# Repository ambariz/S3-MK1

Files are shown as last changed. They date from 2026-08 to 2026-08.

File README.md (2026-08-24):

# S3 MK-1

A compact Surveillance Security System built around a sensor-equipped cube and a wearable controller.

The S3 Cube monitors its surroundings using multiple sensors for motion, vibration, orientation, light, temperature, humidity, and sound. The data is sent to the S3 Watch, a small wearable controller with an OLED display and physical buttons for monitoring and controlling the cube.

The project includes custom PCBs designed in KiCad, custom component footprints, ESP8266 firmware, and fully 3D-printed enclosures designed in Onshape.

| S3 MK-1 Cube | S3 MK-1 Watch |
|---|---|
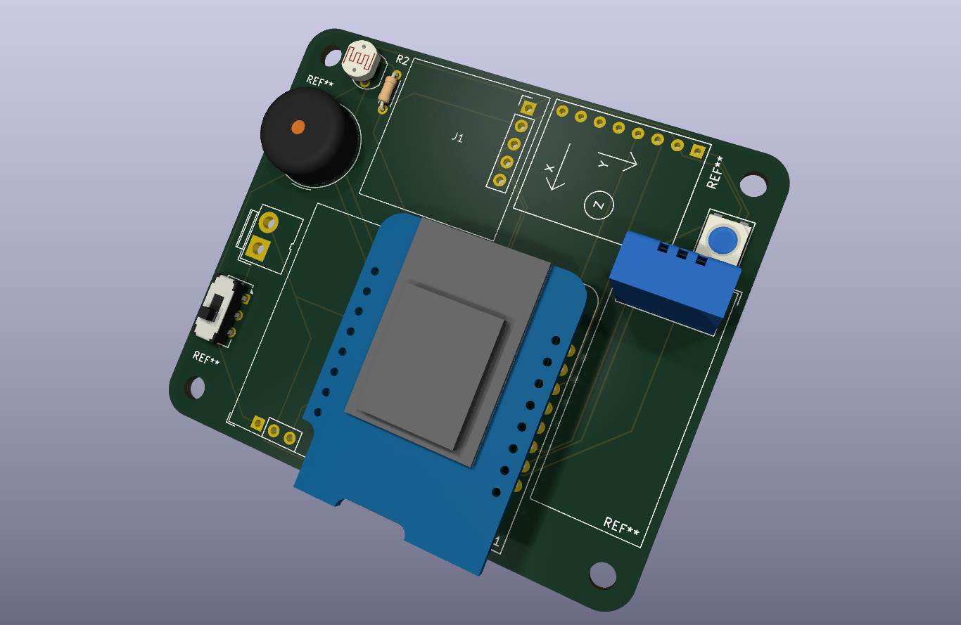
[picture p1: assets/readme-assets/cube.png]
S3 Cube
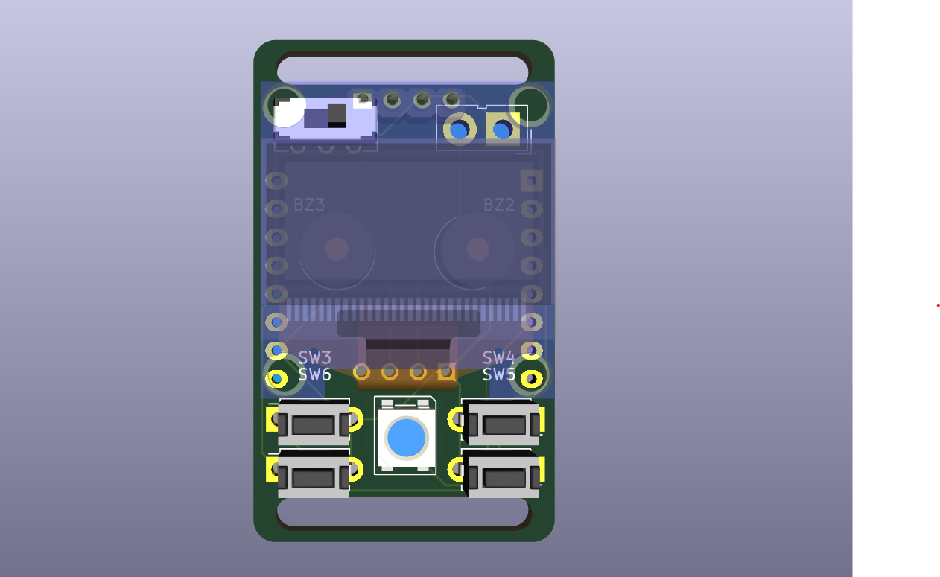
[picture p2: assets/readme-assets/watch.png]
S3 Watch
|  |  |

# Features

- Wireless S3 Cube MK-1 to S3 Watch MK-1 communication
- Motion / Presence detection
- Vibration detection
- Tilt / Orientation detection
- Sound detection
- Light detection
- Temperature & Humidity monitoring
- OLED display
- Physical button controls
- Arm / Disarm system
- Status indication
- Custom KiCad PCBs
- Custom KiCad footprints
- ESP8266 firmware
- 3D-printed enclosures
- Weighted self-orienting cube design
- 20mm watch strap support

## CAD

> **Note:**
> S3 Cube MK-1 enclosure is made for rolling in a plain surface. This's the reason the edges are with R10.

| S3 Cube MK-1 | S3 Watch MK-1 |
|---|---|
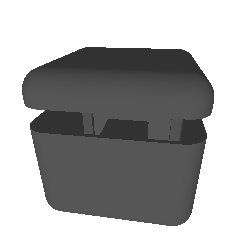
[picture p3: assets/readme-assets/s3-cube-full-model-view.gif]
S3 Cube
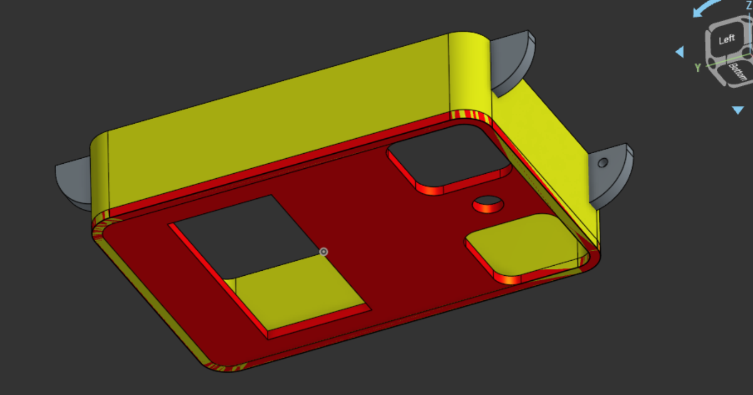
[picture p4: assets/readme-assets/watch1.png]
S3 Watch
|  |  |
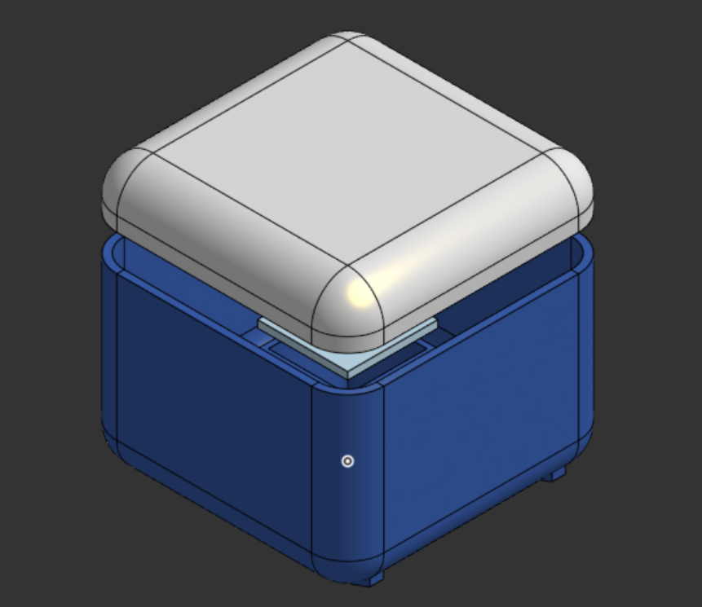
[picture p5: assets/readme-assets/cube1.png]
S3 Cube
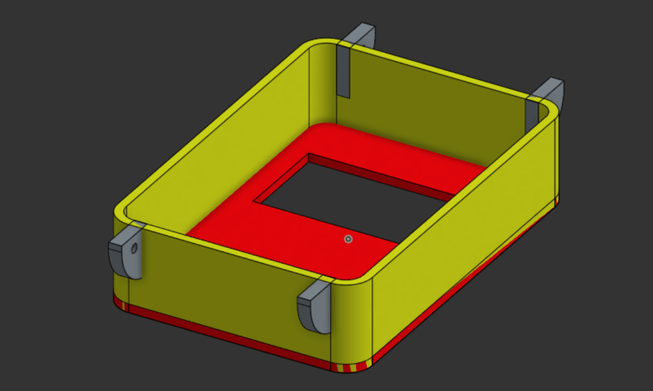
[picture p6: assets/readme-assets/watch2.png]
S3 Watch
|  |  |

## PCB

> **Note:**  
> The S3 Watch PCB is designed with a 20mm strap support, If you are 3D printing the enclosure for the watch, Feel free to break it with pliers.

| S3 MK-1 Cube PCB | S3 MK-1 Watch PCB |
|---|---|
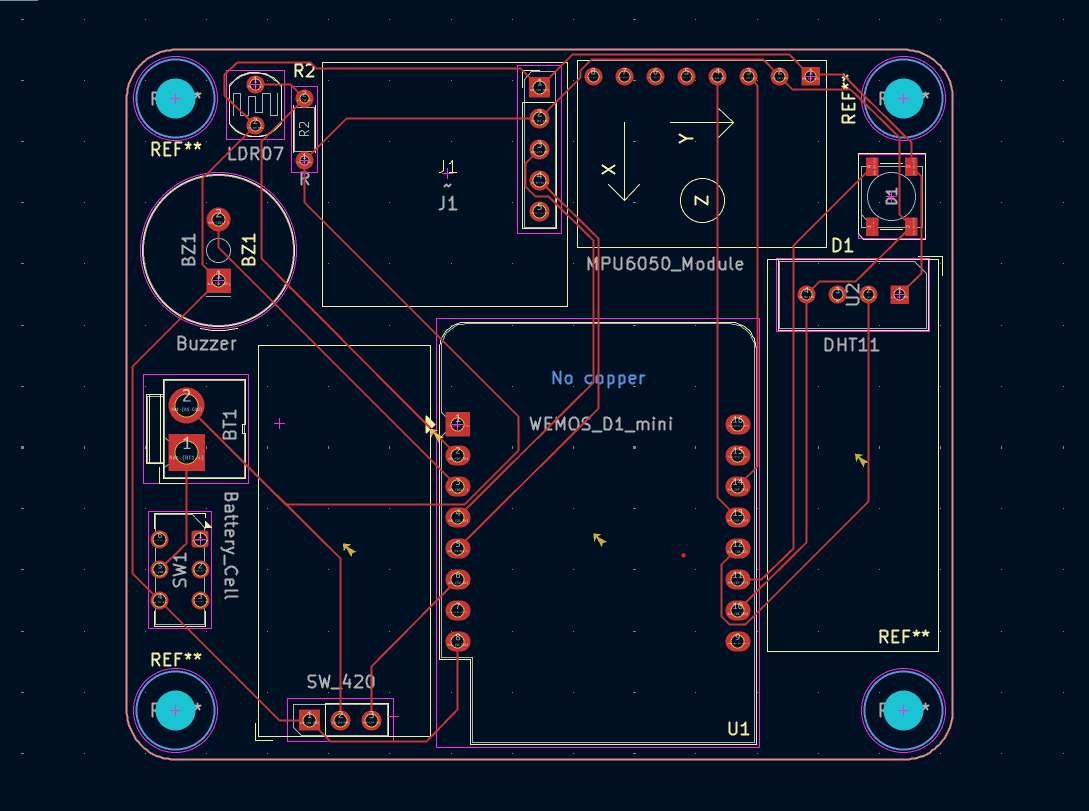
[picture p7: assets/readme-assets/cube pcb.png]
Cube PCB
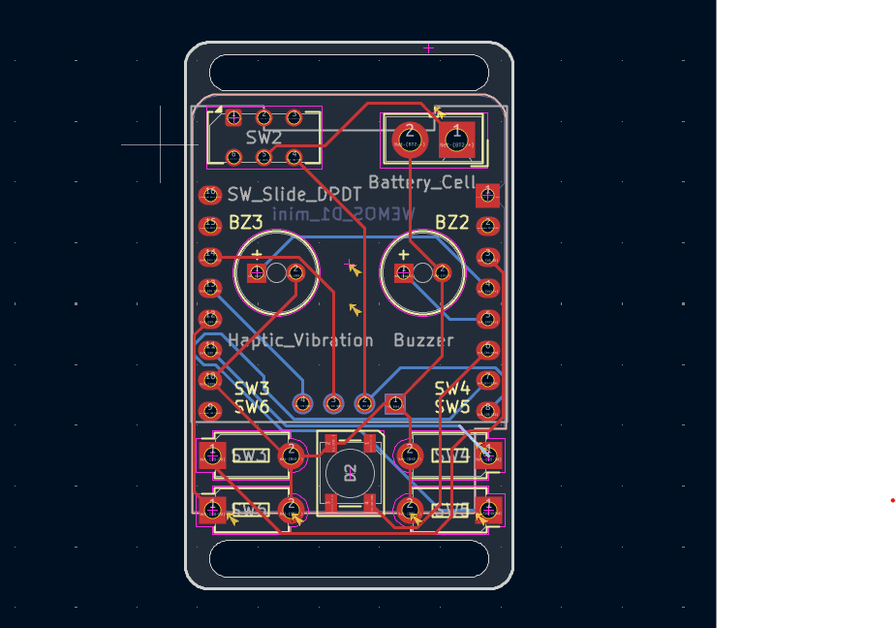
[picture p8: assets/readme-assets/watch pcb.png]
Watch PCB
|  |  |
| Cube PCB | Watch PCB |

## Schematic

> **Note:**  
> The preview images may be scaled down and lose detail. Use the journal.md for a clear, full-resolution view.

| S3 MK-1 Cube | S3 MK-1 Watch |
|---|---|
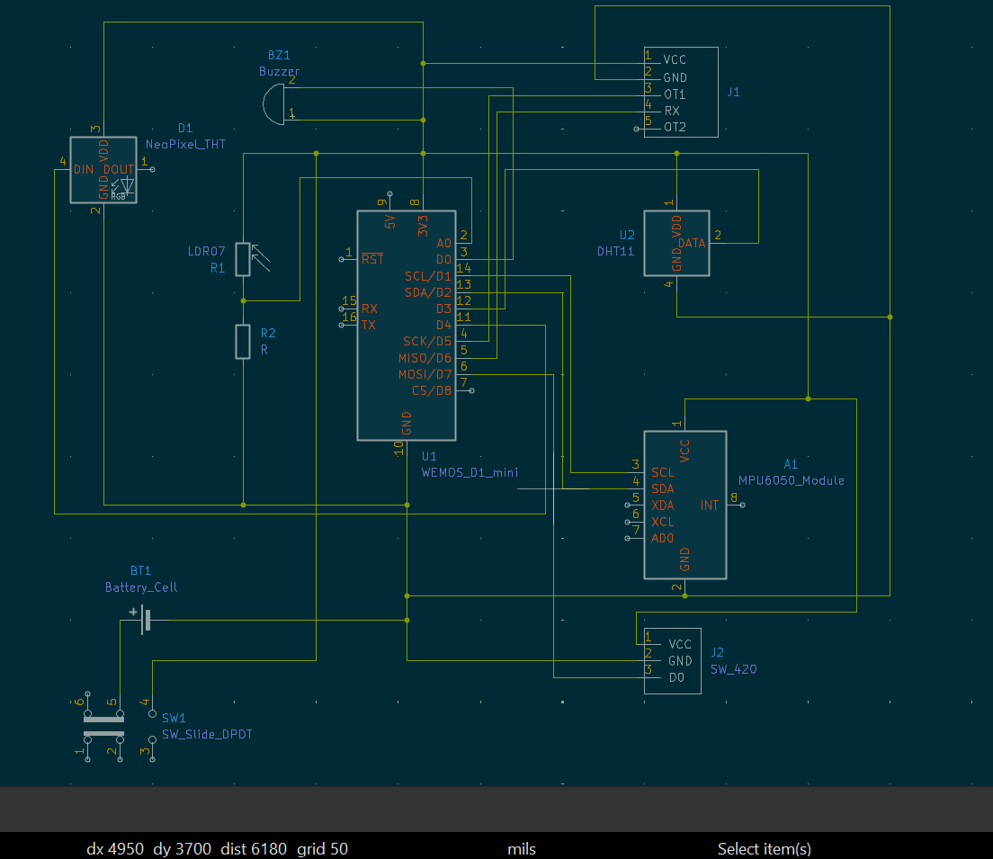
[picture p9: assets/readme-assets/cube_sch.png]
Cube PCB
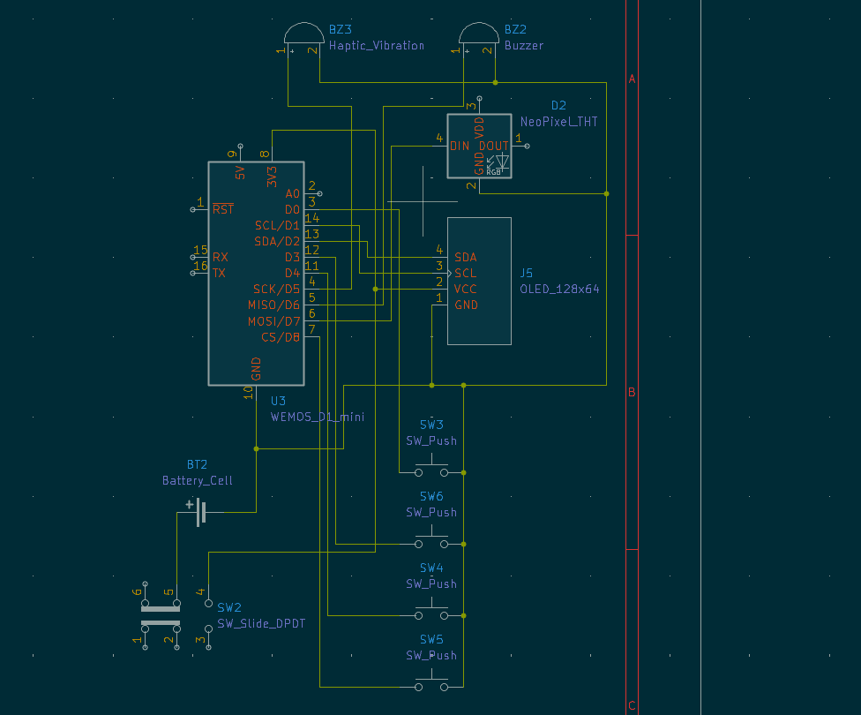
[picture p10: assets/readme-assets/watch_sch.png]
Watch PCB
|  |  |

## BOM

| Product | Quantity | Source | Price (INR) | Link |
| :--- | :--- | :--- | :--- | :--- |
| D1 Mini ESP8266 | 2 | Robu | 199 | [Product Link](https://robu.in/product/d1-mini-v2-nodemcu-4m-bytes-lua-wifi-internet-of-things-development-board-based-esp8266/) |
| mmWave Sensor HLK-LD2410-AA | 1 | Robu | 639 | [Product Link](https://robu.in/product/hi-link-hlk-ld2410s/) |
| SW-420 Vibration Sensor Module | 1 | Robu | 42 | [Product Link](https://robu.in/product/vibration-sensor-module-alarm-motion-sensor-module-vibration-switch-sw-420/) |
| MPU-6050 3-Axis Accelerometer and Gyro Sensor | 1 | Robu | 154 | [Product Link](https://robu.in/product/mpu-6050-gyro-sensor-2-accelerometer/) |
| LDR 5mm | 1 | Robu | 59 | [Product Link](https://robu.in/product/1-month-warranty-1307/) |
| DHT11 | 1 | Robu | 51 | [Product Link](https://robu.in/product/dht11-digital-relative-humidity-temperature-sensor-module/) |
| LiPo Battery | 2 | Robu | 219 | [Product Link](https://robu.in/product/400mah-pcm-protected-micro-li-po-battery/) |
| Slide Switch | 2 | Robu | 2 | [Product Link](https://robu.in/product/1-month-warranty-255/) |
| Neopixel 5050 | 2 | Robu | 176 | [Product Link](https://robu.in/product/ws2812b-rgb-addressable-led-module/) |
| Buzzer | 2 | Robu | 47 | [Product Link](https://robu.in/product/1-month-warranty-1248/) |
| Tactile Push Button Switch | 4 | Robu | 1.26 | [Product Link](https://robu.in/product/6x6x5mm-tactile-push-button-switch-pack-of-20/) |
| ERM Coin Vibration Motor | 1 | Robu | 77 | [Product Link](https://robu.in/product/erm-coin-vibration-motor-d10mm-w-3-4mm/) |

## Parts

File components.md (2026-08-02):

## Cube
### Controller
- ESP8266 D1 Mini
(we are using D1 mini because it's small and fits perfectly inside cube)

### Motion
- mmWave sensor HLK-LD2410-AA

### Vibration
- SW-420 Vibration Sensor

### Angle / Tilt
- MPU6050
(this sensor have 3 axis accelerometer and Gyro)

### Light
- LDR

### Temperature
- DHT11

### Humidity
- DHT11

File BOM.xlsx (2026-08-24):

Product | Quantity | Source | Price (INR) Per Item | Link
D1 Mini ESP8255 | 2 | Robu | 199 | Link to Buy (https://robu.in/product/d1-mini-v2-nodemcu-4m-bytes-lua-wifi-internet-of-things-development-board-based-esp8266/)
mmWave sensor HLK-LD2410-AA | 1 | Robu | 639 | Link to Buy (https://robu.in/product/hi-link-hlk-ld2410s/)
SW-420 Vibration Sensor Module | 1 | Robu | 42 | Link to Buy (https://robu.in/product/vibration-sensor-module-alarm-motion-sensor-module-vibration-switch-sw-420/)
MPU-6050 3-Axis Accelerometer and Gyro Sensor | 1 | Robu | 154 | Link to Buy (https://robu.in/product/mpu-6050-gyro-sensor-2-accelerometer/)
LDR 5mm | 1 | Robu | 59 | Link to Buy (https://robu.in/product/1-month-warranty-1307/)
DHT11 | 1 | Robu | 51 | Link to Buy (https://robu.in/product/dht11-digital-relative-humidity-temperature-sensor-module/)
LiPo Battery | 2 | Robu | 219 | Link to Buy (https://robu.in/product/400mah-pcm-protected-micro-li-po-battery/)
Slide Switch | 2 | Robu | 2 | Link to Buy (https://robu.in/product/1-month-warranty-255/)
Neopixel 5050 | 2 | Robu | 176 | LInk to Buy (https://robu.in/product/ws2812b-rgb-addressable-led-module/)
Buzzer | 2 | Robu | 47 | Link to Buy (https://robu.in/product/1-month-warranty-1248/)
Tactile Push Button Switch | 4 | Robu | 1.26 | Link to Buy (https://robu.in/product/6x6x5mm-tactile-push-button-switch-pack-of-20/)
ERM Coin Vibration Motor | 1 | Robu | 77 | Link to Buy (https://robu.in/product/erm-coin-vibration-motor-d10mm-w-3-4mm/)

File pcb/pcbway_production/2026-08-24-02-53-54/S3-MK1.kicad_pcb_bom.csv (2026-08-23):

Designator | Quantity | Value | Footprint | Package | MPN | DNP | Mount_Type | Description | Sim.Device | Sim.Type | Sim.Pins | KiLib_Generator
A1 | 1 | MPU6050_Module | MPU6050_Module |  |  |  | tht
BT1, BT2 | 2 | Battery_Cell | Battery_LiPo_Custom |  |  |  | tht | Single-cell battery | V | DC | 1=+ 2=-
BZ1 | 1 | Buzzer | Buzzer_TDK_PS1240P02BT_D12.2mm_H6.5mm |  |  |  | tht | Buzzer, polarized
BZ2 | 1 | Buzzer | MagneticBuzzer_Kingstate_KCG0601 |  |  |  | tht | Buzzer, polarized
BZ3 | 1 | Haptic_Vibration | MagneticBuzzer_Kingstate_KCG0601 |  |  |  | tht | Vibration
D1, D2 | 2 | NeoPixel_THT | LED_SK6812_PLCC4_5.0x5.0mm_P3.2mm |  |  |  | smt | RGB LED with integrated controller, 5mm/8mm LED package
J1 | 1 | ~ | LD2420_custom |  |  |  | tht | HLK LD2420
J2 | 1 | SW_420 | Vibration_sensor_SW420_custom |  |  |  | tht
J3 | 1 | audio_sensor_custom | Audio_sensor_custom |  |  |  | tht
J5 | 1 | OLED_128x64 | OLED_128x64 |  |  |  | tht
R1 | 1 | LDR07 | R_LDR_5.1x4.3mm_P3.4mm_Vertical |  |  |  | tht | light dependent resistor
R2 | 1 | R | R_Axial_DIN0204_L3.6mm_D1.6mm_P5.08mm_Horizontal |  |  |  | tht | Resistor |  |  |  | resistor/THT
SW1, SW2 | 2 | SW_Slide_DPDT | SW_CK_JS202011CQN_DPDT_Straight |  |  |  | tht | Slide Switch, dual pole double throw
SW3, SW4, SW5, SW6 | 4 | SW_Push | SW_PUSH_1P1T_6x3.5mm_H4.3_APEM_MJTP1243 |  |  |  | tht | Push button switch, generic, two pins
U1, U3 | 2 | WEMOS_D1_mini | WEMOS_D1_mini_light |  |  |  | tht | 32-bit microcontroller module with WiFi
U2 | 1 | DHT11 | Aosong_DHT11_5.5x12.0_P2.54mm |  |  |  | tht | 3.3V to 5.5V, temperature and humidity module, DHT11

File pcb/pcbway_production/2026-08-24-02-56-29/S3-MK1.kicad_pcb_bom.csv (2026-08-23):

Designator | Quantity | Value | Footprint | Package | MPN | DNP | Mount_Type | Description | Sim.Device | Sim.Type | Sim.Pins | KiLib_Generator
A1 | 1 | MPU6050_Module | MPU6050_Module |  |  |  | tht
BT1 | 1 | Battery_Cell | Battery_LiPo_Custom |  |  |  | tht | Single-cell battery | V | DC | 1=+ 2=-
BZ1 | 1 | Buzzer | Buzzer_TDK_PS1240P02BT_D12.2mm_H6.5mm |  |  |  | tht | Buzzer, polarized
D1 | 1 | NeoPixel_THT | LED_SK6812_PLCC4_5.0x5.0mm_P3.2mm |  |  |  | smt | RGB LED with integrated controller, 5mm/8mm LED package
J1 | 1 | ~ | LD2420_custom |  |  |  | tht | HLK LD2420
J2 | 1 | SW_420 | Vibration_sensor_SW420_custom |  |  |  | tht
J3 | 1 | audio_sensor_custom | Audio_sensor_custom |  |  |  | tht
R1 | 1 | LDR07 | R_LDR_5.1x4.3mm_P3.4mm_Vertical |  |  |  | tht | light dependent resistor
R2 | 1 | R | R_Axial_DIN0204_L3.6mm_D1.6mm_P5.08mm_Horizontal |  |  |  | tht | Resistor |  |  |  | resistor/THT
SW1 | 1 | SW_Slide_DPDT | SW_CK_JS202011CQN_DPDT_Straight |  |  |  | tht | Slide Switch, dual pole double throw
U1 | 1 | WEMOS_D1_mini | WEMOS_D1_mini_light |  |  |  | tht | 32-bit microcontroller module with WiFi
U2 | 1 | DHT11 | Aosong_DHT11_5.5x12.0_P2.54mm |  |  |  | tht | 3.3V to 5.5V, temperature and humidity module, DHT11

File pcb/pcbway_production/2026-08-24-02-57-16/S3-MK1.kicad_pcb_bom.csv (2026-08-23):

Designator | Quantity | Value | Footprint | Package | MPN | DNP | Mount_Type | Description | Sim.Device | Sim.Type | Sim.Pins
BT2 | 1 | Battery_Cell | Battery_LiPo_Custom |  |  |  | tht | Single-cell battery | V | DC | 1=+ 2=-
BZ2 | 1 | Buzzer | MagneticBuzzer_Kingstate_KCG0601 |  |  |  | tht | Buzzer, polarized
BZ3 | 1 | Haptic_Vibration | MagneticBuzzer_Kingstate_KCG0601 |  |  |  | tht | Vibration
D2 | 1 | NeoPixel_THT | LED_SK6812_PLCC4_5.0x5.0mm_P3.2mm |  |  |  | smt | RGB LED with integrated controller, 5mm/8mm LED package
J5 | 1 | OLED_128x64 | OLED_128x64 |  |  |  | tht
SW2 | 1 | SW_Slide_DPDT | SW_CK_JS202011CQN_DPDT_Straight |  |  |  | tht | Slide Switch, dual pole double throw
SW3, SW4, SW5, SW6 | 4 | SW_Push | SW_PUSH_1P1T_6x3.5mm_H4.3_APEM_MJTP1243 |  |  |  | tht | Push button switch, generic, two pins
U3 | 1 | WEMOS_D1_mini | WEMOS_D1_mini_light |  |  |  | tht | 32-bit microcontroller module with WiFi

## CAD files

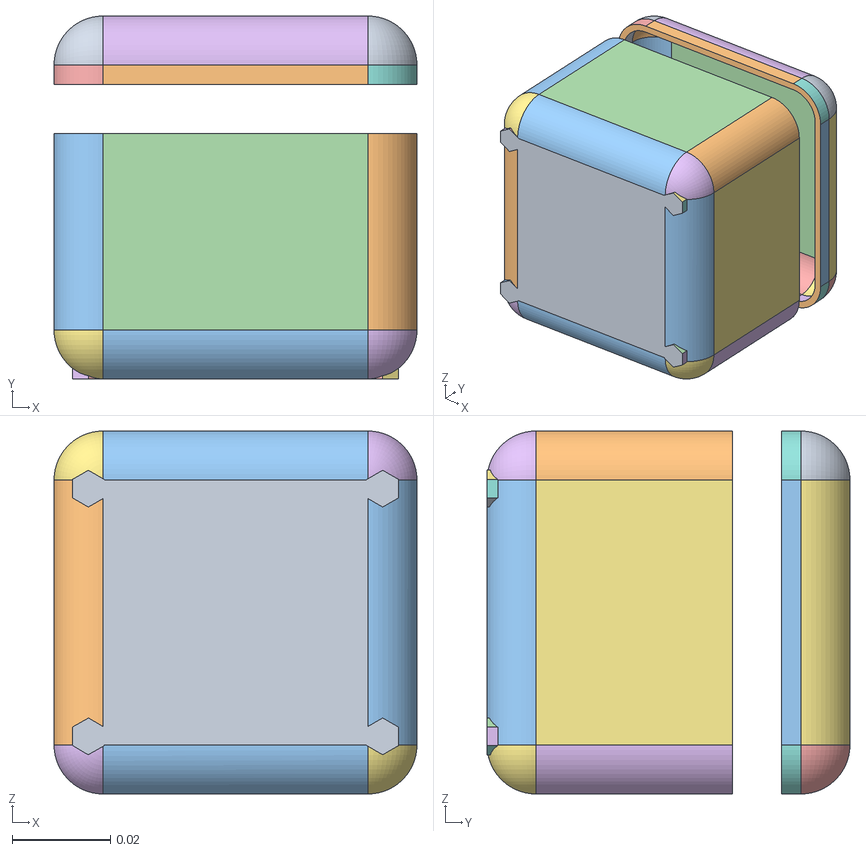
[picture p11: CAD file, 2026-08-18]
cad/s3-cube-enclosure-cad/s3-cube-full-model-view.obj
0.074 x 0.074 x 0.074

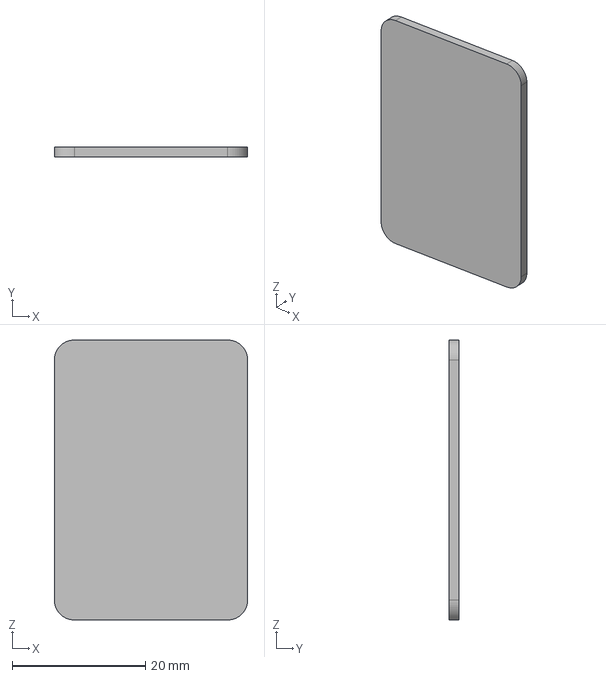
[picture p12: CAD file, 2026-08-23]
cad/s3-watch-enclosure-cad/S3-watch-PCB-back-plate.step
29.0 x 1.50 x 42.0 mm

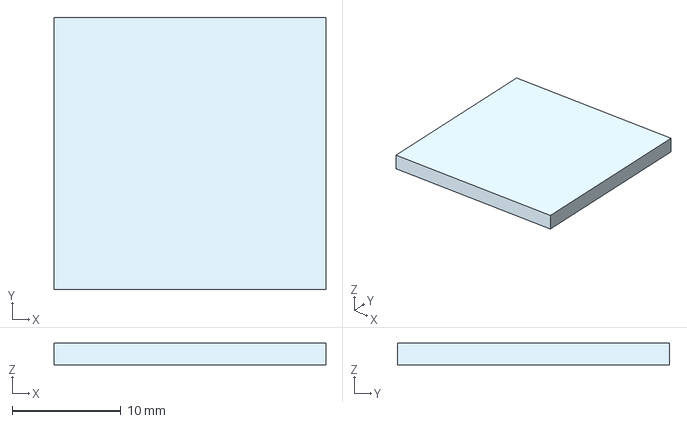
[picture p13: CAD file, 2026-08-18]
cad/s3-cube-enclosure-cad/s3-cube-inner-top-enclosure.step
25.0 x 25.0 x 2.00 mm

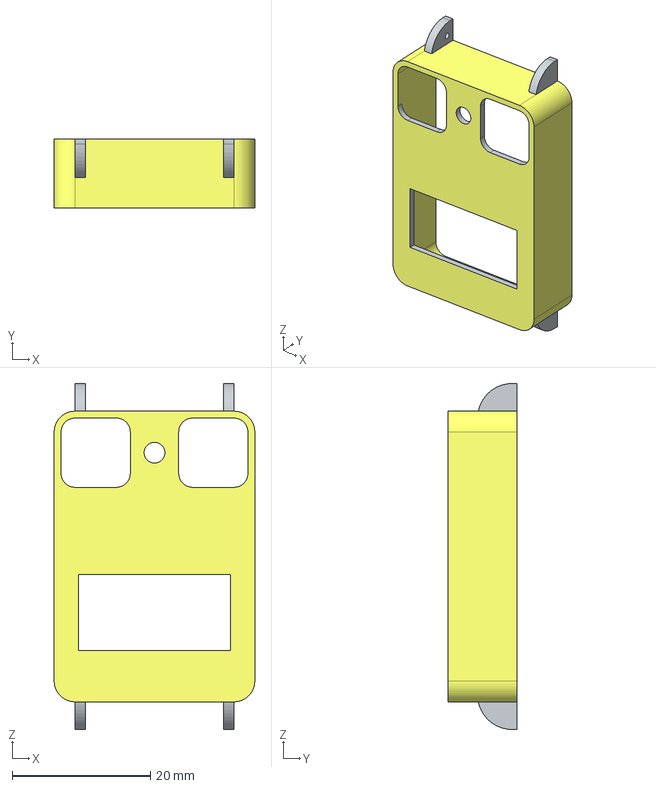
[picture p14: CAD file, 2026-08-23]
cad/s3-watch-enclosure-cad/S3-watch-PCB-case.step
29.0 x 10.0 x 50.0 mm

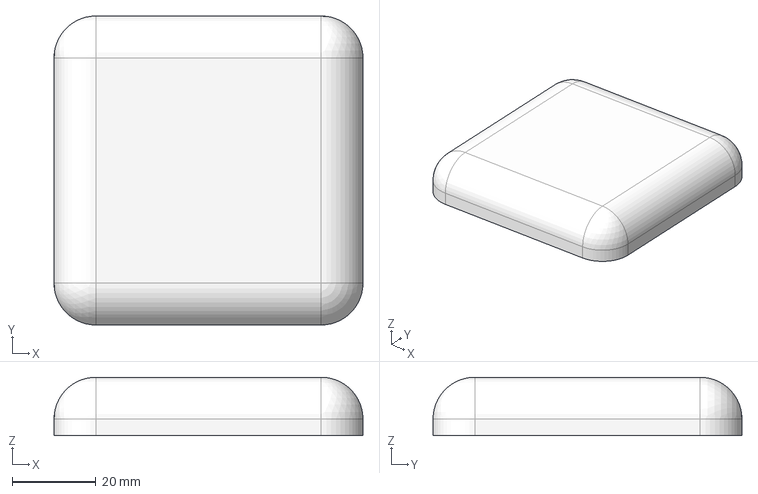
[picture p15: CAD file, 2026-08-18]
cad/s3-cube-enclosure-cad/s3-cube-top-enclosure.step
74.0 x 74.0 x 14.0 mm

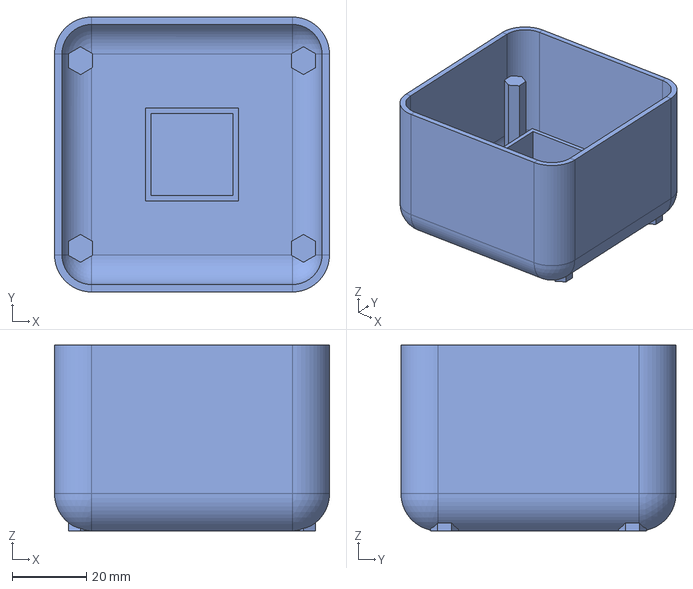
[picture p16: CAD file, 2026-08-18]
cad/s3-cube-enclosure-cad/s3-cube-base-enclosure.step
74.0 x 74.0 x 50.0 mm

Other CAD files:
cad/s3-cube-enclosure-cad/s3-cube-base-enclosure.3mf
cad/s3-cube-enclosure-cad/s3-cube-base-enclosure.stl
cad/s3-cube-enclosure-cad/s3-cube-inner-top-enclosure.3mf
cad/s3-cube-enclosure-cad/s3-cube-inner-top-enclosure.stl
cad/s3-cube-enclosure-cad/s3-cube-top-enclosure.3mf
cad/s3-cube-enclosure-cad/s3-cube-top-enclosure.stl
cad/s3-watch-enclosure-cad/S3-watch-PCB-back-plate.3mf
cad/s3-watch-enclosure-cad/S3-watch-PCB-back-plate.stl
cad/s3-watch-enclosure-cad/S3-watch-PCB-case.3mf
cad/s3-watch-enclosure-cad/S3-watch-PCB-case.stl

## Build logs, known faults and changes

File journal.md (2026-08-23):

# date:02/08/2026
# time spent:1.5hr
## description:
I made a blueprint for S3 Mark 1, I researched for features and possibilities which can be built in MK1. I learned about making a blueprint diagram, I'm attaching the image too. In that you can see the diagram for S3 cube and it's controller. The S3 cube will do three S ( Surveillance Security System ) and send it to the controller. Controller will have the display, LEDs, and few buttons for arming and disarming the cube. 

The cube will have the following surveillance features :
- Motion
- Sound
- Vibration
- Angle
- Video (not possible ig)
- Light 
- Temperature
- Humidity
## images:
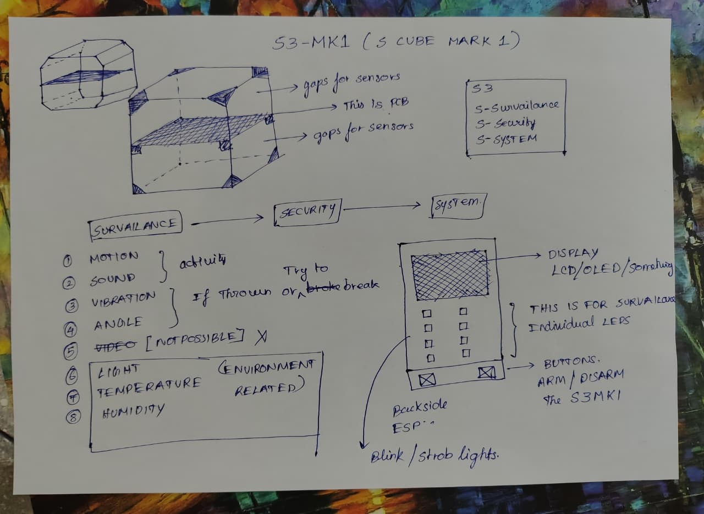
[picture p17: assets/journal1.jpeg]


------
# date:02/08/2026
# time spent:0.5hr
## description:
For the features, I searched for the sensors and listed it down in the components.md, placed the components in kicad schematic.

| | | |
|---|---|---|
| **Controller** | ESP8266 D1 Mini | Small and fits perfectly inside the cube |
| **Motion** | HLK-LD2410-AA mmWave Sensor | Motion and presence detection |
| **Vibration** | SW-420 Vibration Sensor | Vibration detection |
| **Angle / Tilt** | MPU6050 | 3-axis accelerometer + 3-axis gyroscope |
| **Light** | LDR | Ambient light detection |
| **Temperature** | DHT11 | Temperature measurement |
| **Humidity** | DHT11 | Humidity measurement |

Footprint is not available for HLK-LD2410-AA, SW-420 , MPU6050, DHT11 in kicad. So I'm making custom footprints for the components.

------
# date:04/08/2026
# time spent:1hr
## description:
Since footprint is not available for HLK-LD2410-AA, SW-420 , MPU6050 in kicad. So I made custom footprints for the missing component's symbol and footprint. 
I searched for the exact component model and pinout, matching it with the datasheet and created custom symbols and footprints.
Now all the components for the circuit is ready and in place.
## images:
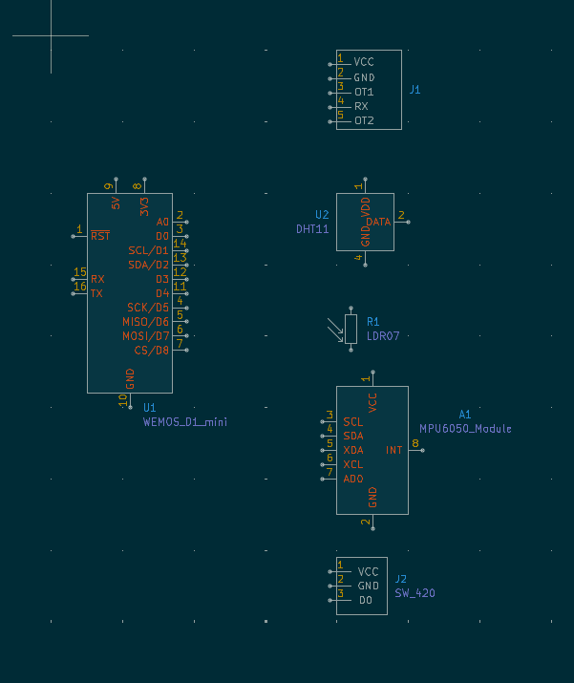
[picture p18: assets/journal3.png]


------
# date:09/08/2026
# time spent:1.5hr
## description:
I connected the components and added footprints but most of the footprints were not there so I created custom footprints for the components and connected them. I added few more symbols for battery, DPDT slide switch, 5050 neopixel led for showing the status, connected them too.
After connecting I started arranging them in PCB editor.
## images:

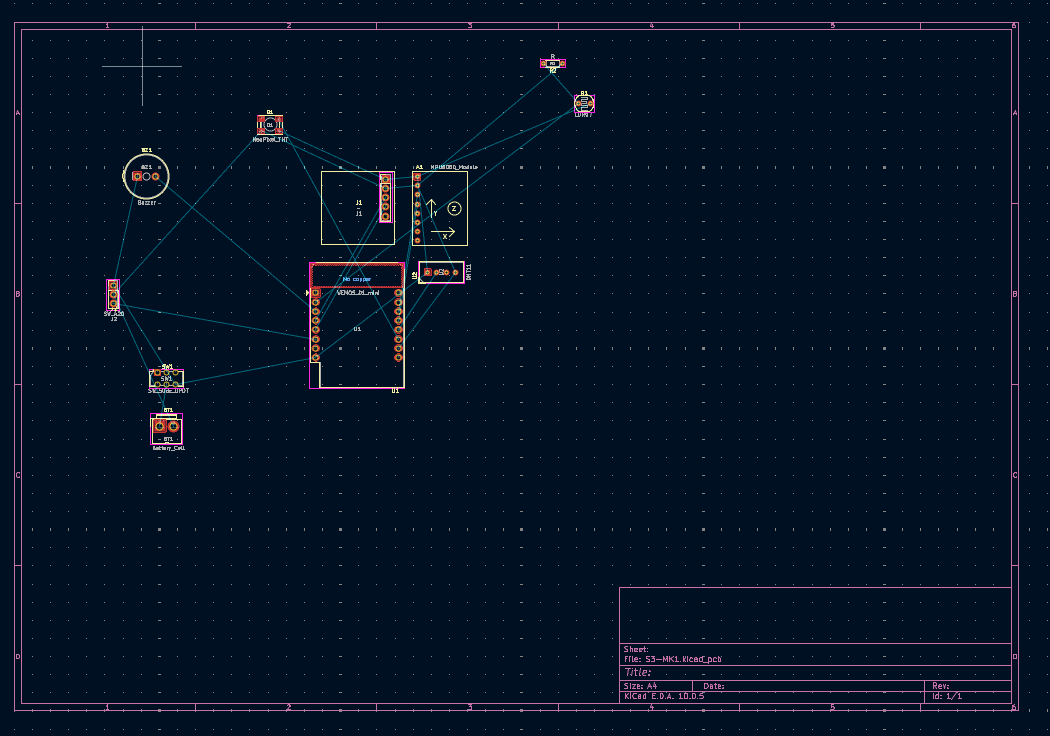
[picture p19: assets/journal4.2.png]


------
# date:09/08/2026
# time spent:1hr
## description:
I started assembling the footprints in PCB editor for S3 MK-1, drew a PCB of 8x8cm and tried to fit all the components footprint inside the box. The initial plan is to create a enclosure for this PCB,So I added M3 screws since this will be inside a box, and after a lot of movements I reduced the PCB size into 66.5mm X 57mm PCB. Now footprint placement is complete next I will route them one by one.
## images:
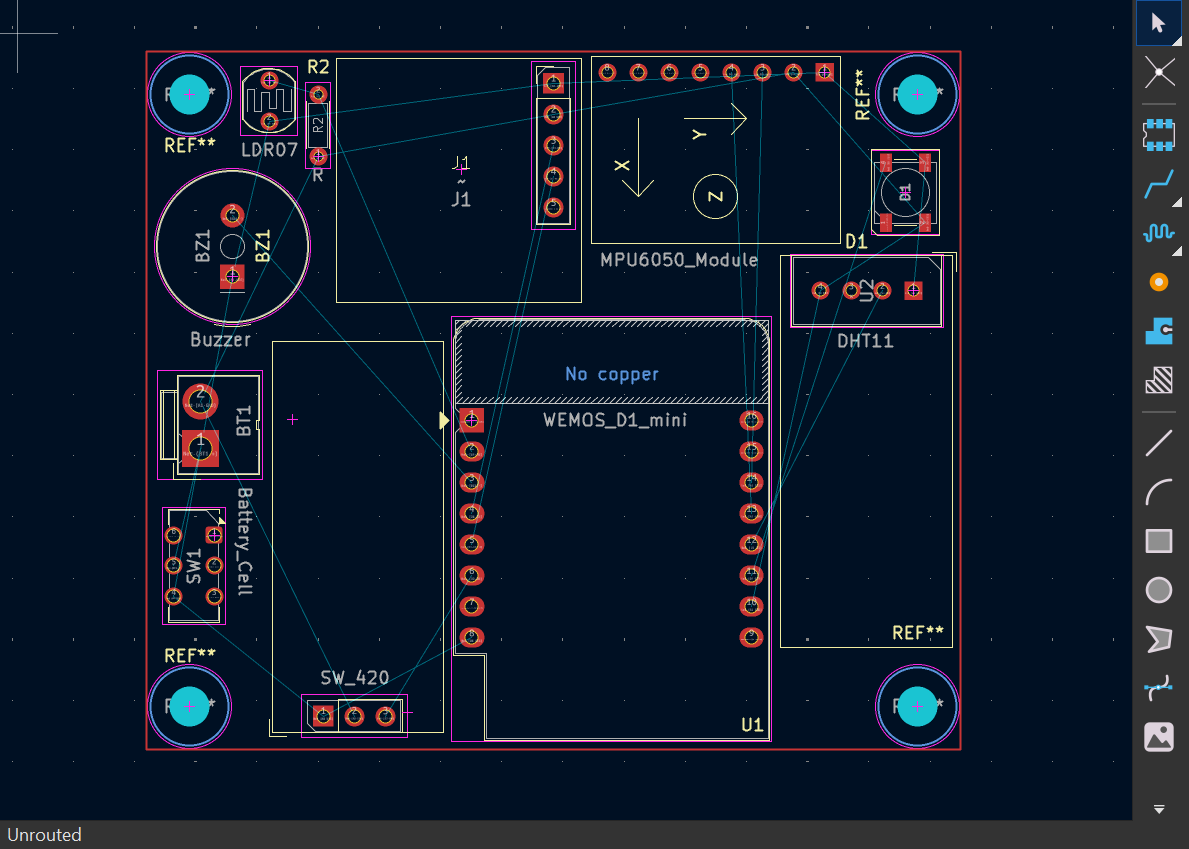
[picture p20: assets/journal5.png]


------
# date:10/08/2026
# time spent:1hr
## description:
I started routing the PCB, Before routing I checked for errors in the circuit with DRC, I got two errors and few warnings, Error: Footprint has malformed courtyard (not a closed shape). I resolved this by correcting the F.courtyard position in the footprint. After solving this issues I started routing the PCB manually, after few revisions I completed the routing (not the best routing but I'm able to connect all the terminal pads) after routing I checked for the errors.. there are no errors, I viewed the pcb in 3D viewer now the PCB is looking very good. Next is the check for few more components I'm thinking of adding.
## images:



------
# date:12/08/2026
# time spent:1.5hr
## description:
I wrote firmware for S3 cube, All the components data is now able to sense by the esp8266, this firmware is the initial version which does not include the communication. And while writing the firmware I thought of adding a Audio detection in the S3 cube, so I went back to KiCAD and created a custom symbol (footprint not yet created). And placed it in the circuit and connected it. This audio sensor will help to find noise or sound alerts.

I'm attaching a sample image of firmware I took while writing this! Plese check the repo for full firmware.
## images:
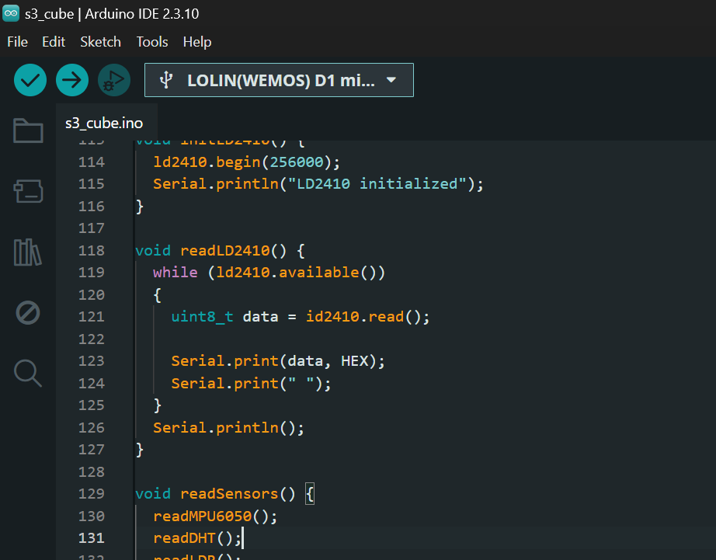
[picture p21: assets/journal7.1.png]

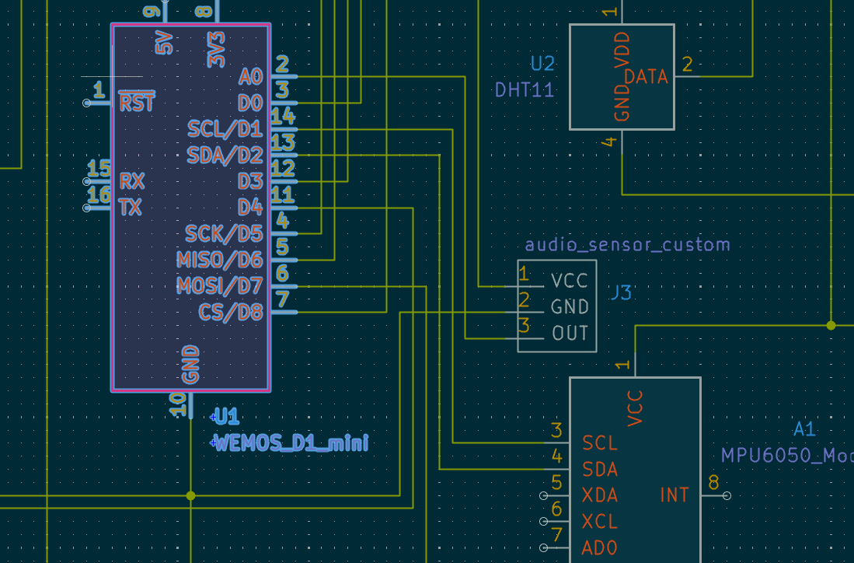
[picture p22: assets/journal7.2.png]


------
# date:13/08/2026
# time spent:1.5hr
## description:
I made custom footprint for audio sensor, and reconnected the whole circuit and PCB. I started making the circuit for S3 watch which will communicate with the S3 cube, I wrote down all the ideas, features and components required of the S3 watch. And wrote down all the required measurements for the S3 cube since we'll be needing a CAD for the enclosure for S3 cube. All the components are placed and started connecting it. For footprints I'm using ScottoKiCad repository, I used this repository for blueprint. Next is to complete the connection and creating the PCB of S3 watch.
## images:
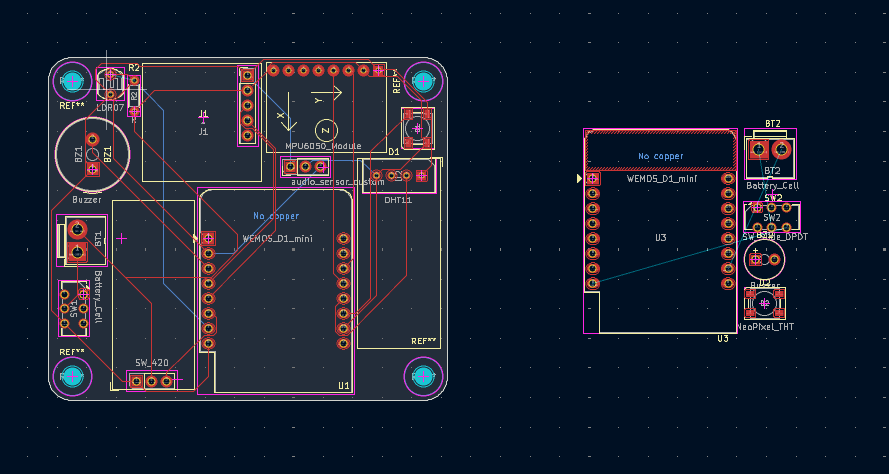
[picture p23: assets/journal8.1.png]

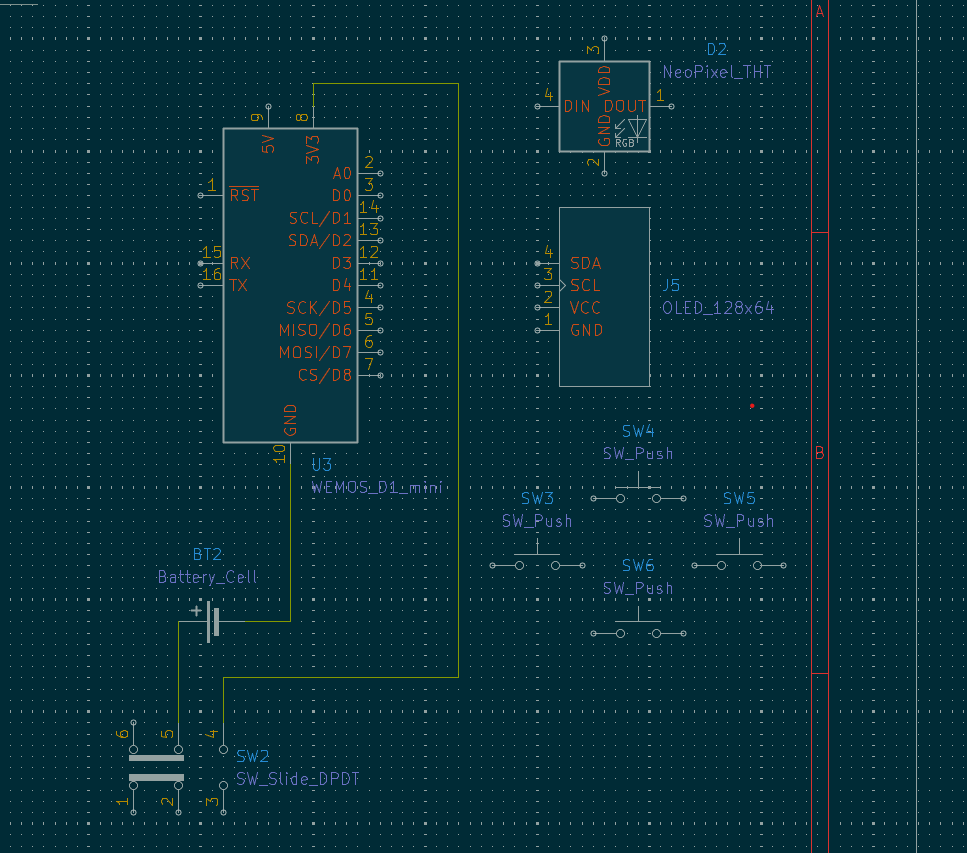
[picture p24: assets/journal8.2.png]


------
# date:13/08/2026
# time spent:2hr
## description:
I created the PCB for S3 watch, initial design was large but after lot of tries and moving the components in right order, I came up with the best possible PCB. Which is small in size (smallest) I'm using D1 mini, I added all the components inside the dimentions of the D1 mini itself. Instead of using regular size components I'm using the mini versions of it, for eg, instead of normal push button I'm using two terminal mini push buttons. 
Next is to complete the PCB, I'm thinking of adding a strap cutout in the pcb itself or I can create a strap mechanism while doing enclosure CAD but I've to think on this :)
## images:
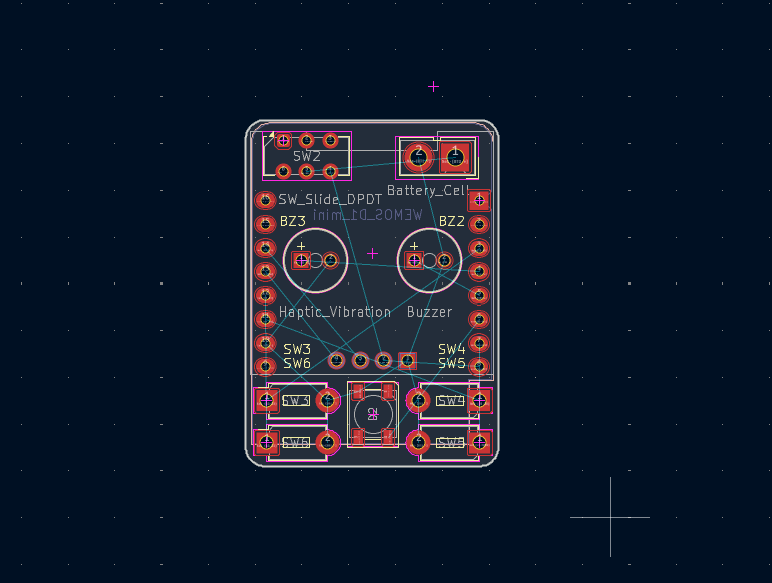
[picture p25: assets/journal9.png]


------
# date:16/08/2026
# time spent:1hr
## description:
I connected the S3 watch PCB with 2 layers, After few revisions the S3 watch PCB connection is without the errors in DRC, and also researched on watches about how the strap (strap is the part which connected to the watch, band like thing) and I found there are fixed sizes available like 18mm, 20mm, 22mm these are the widely used ones. I went with 20mm because 22mm will be too big for the PCB and 18mm I think this's small and 20mm is in the middle so went with it. and added a 3.5mm space to slide the strap. And I thought of creating two version of the watches one is with the PCB strap and another with the strap in the enclosure (case of the PCB watch). Next is to write firmware for the S3 watch and I will try to test the firmware I wrote :)
## images:
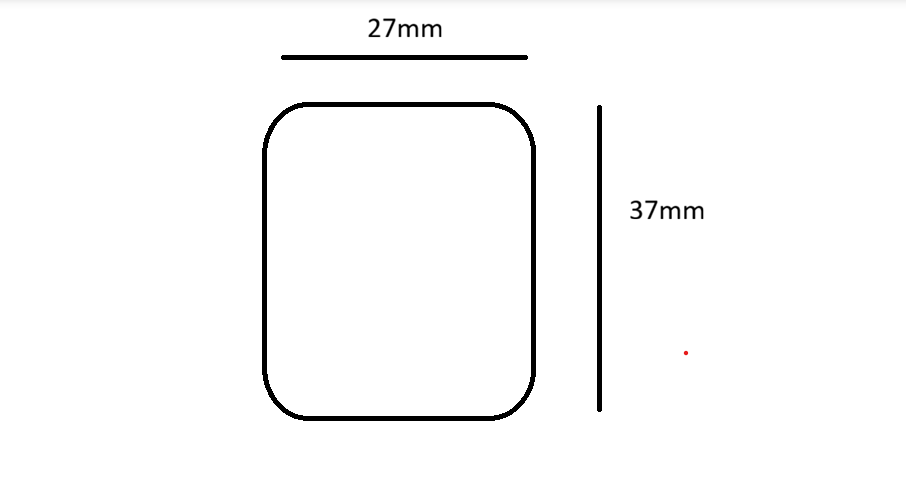
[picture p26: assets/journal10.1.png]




------
# date:17/08/2026
# time spent:1.5hr
## description:
I drew the sketch for the CAD in OnShape, first I measured all the dimentions form the KiCAD PCB, and then drew that in sketch named PCB, and then added drill holes. I created three more sketches one is for innerTop, another is for outerTop. The thickness is 2mm while creating it I came across one issue, if I create a radius of R10 (10mm radius is called R10) so Inner and Outer corner radius is R10 but when i overlap the two sketches in OnShape it's walls are 2mm and then when coming to corners it's getting bit big.. I searched for this issue and found out that ```Outer radius − wall thickness = inner radius``` and it's called inconsistent radius issue.
If my outside is:
70 × 70 × 70 mm
R10 mm
then the inside should be: R9 mm

## images:
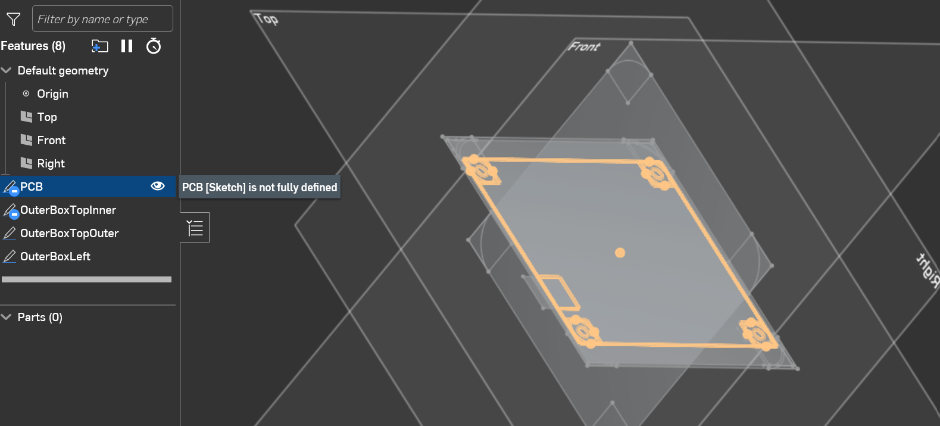
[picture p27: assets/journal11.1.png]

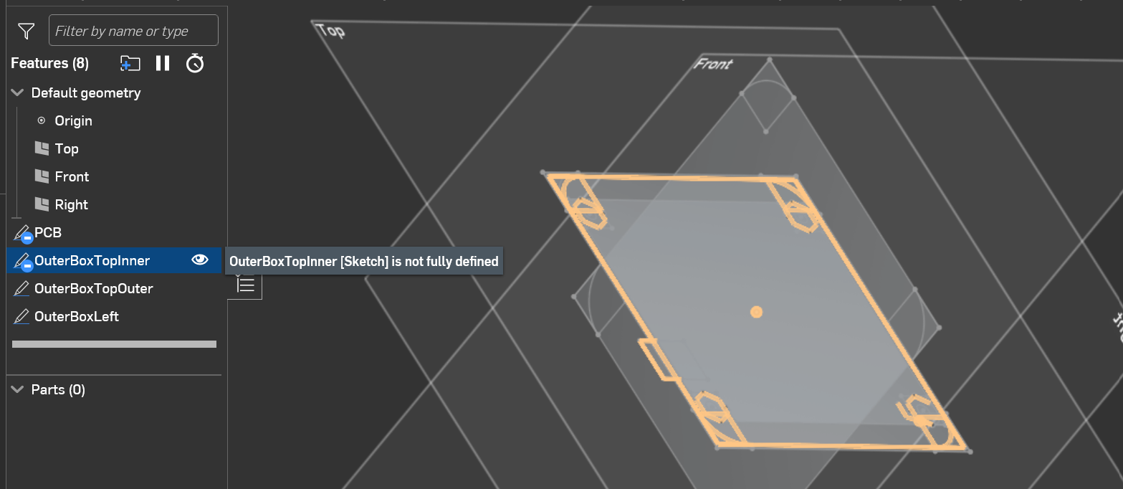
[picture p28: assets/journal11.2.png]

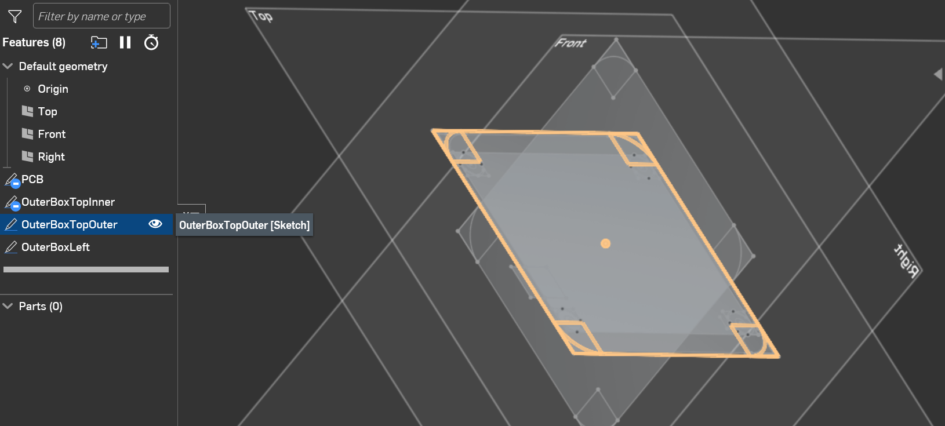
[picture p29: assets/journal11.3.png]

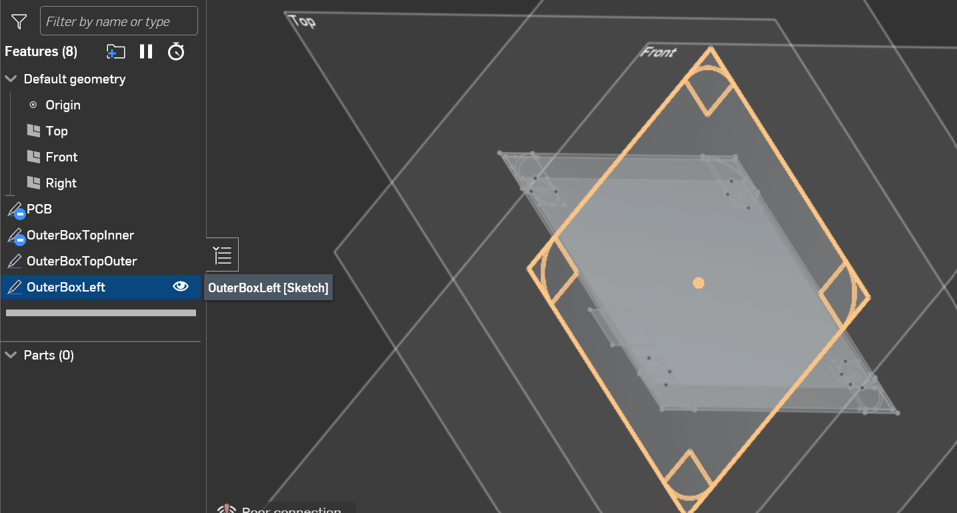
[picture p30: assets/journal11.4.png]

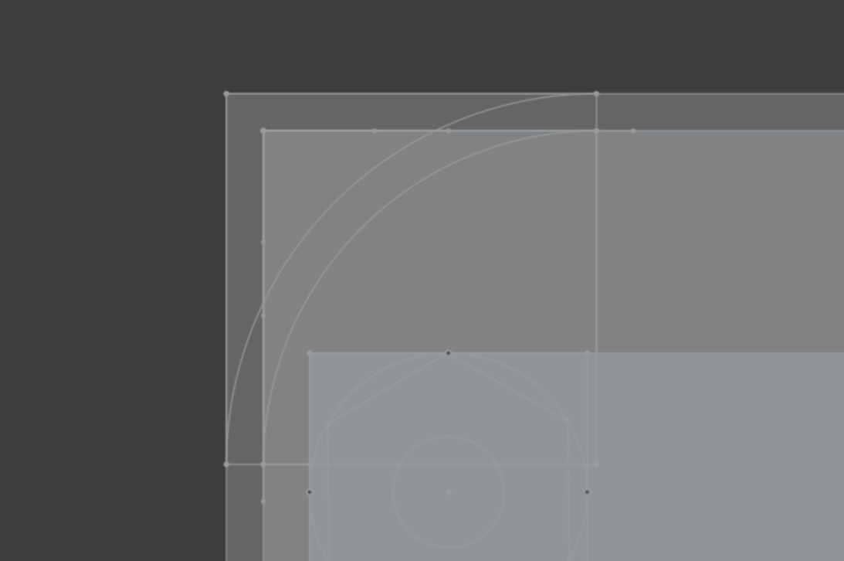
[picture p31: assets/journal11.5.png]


------
# date:18/08/2026
# time spent:1hr
## description:
I started creating the enclosure for S3 Cubed, yesterday I created the sketch for Extrude with the PCB dimentions. Today I did Extrude but when i try to do it for the top and bottom covers, it should be in cuboid shape with R10 so that if we throw this cube this will roll and land in top facing (always!) (yet to do this mechanism) After few revisions I realised, I can do it with the options which are available in the OnShape itself, so just creating a cube and using those pre built options I can create what i want. Next is to complete the enclosure using those and Start sketching the enclosure for the S3 Watch.

## images:
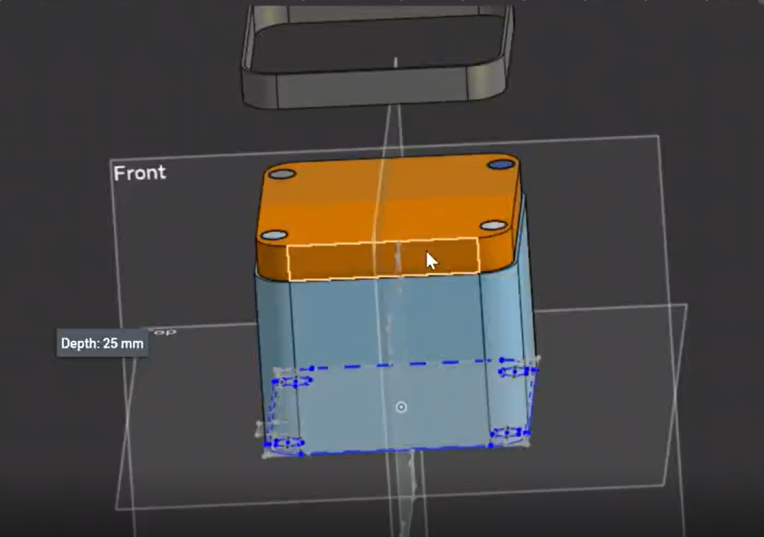
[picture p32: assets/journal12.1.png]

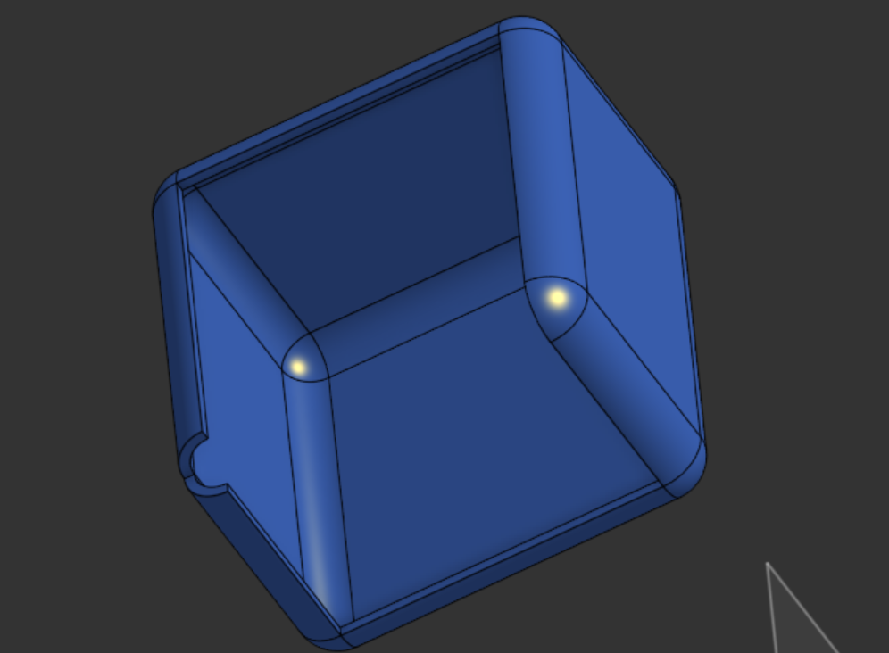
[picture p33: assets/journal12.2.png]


------
# date:18/08/2026
# time spent:1.5hr
## description:
I completed the enclosure of S3 cube. Now I have Base of the cube along with the HEX shaped pillar supports (four of them to support the PCB, we can screw the PCB into this HEX shaped supports), Top cover of the enclosure, we can easily screw and place the top side and also there's inner top side (this inner enclosure is to add weights, I'm thinking of the battery which serves as powersource as well as the wight for the cube). And added all the CAD files in .step .stl and .3mf formats for 3d printing.
Why we need weight in the bottom side of the cube? Because if we throw the cube it should be rolled and the top will come up easily. 

## images:
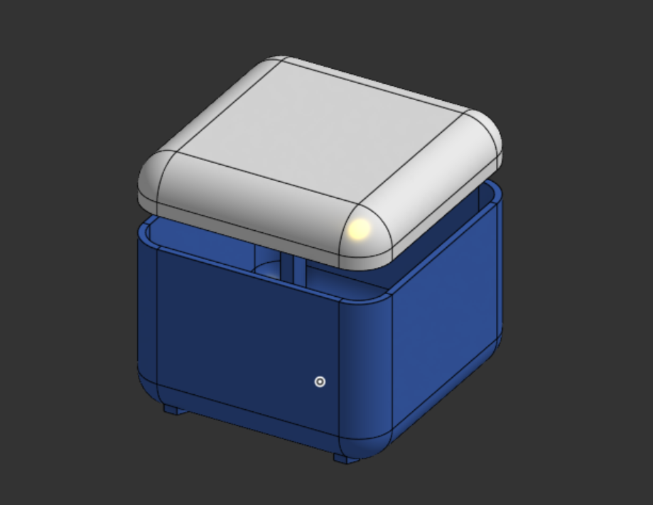
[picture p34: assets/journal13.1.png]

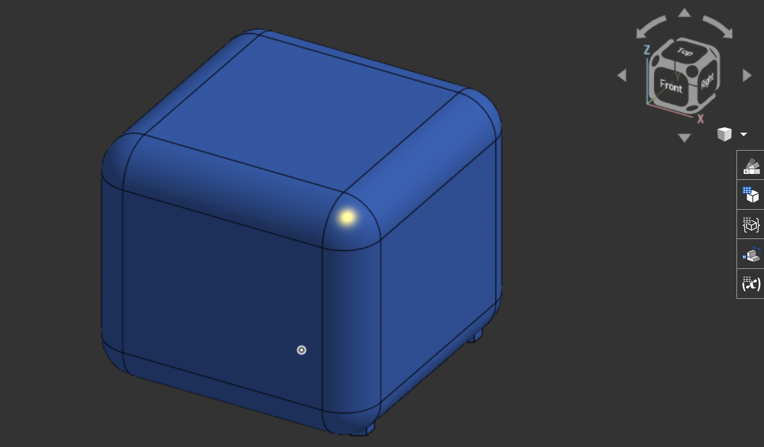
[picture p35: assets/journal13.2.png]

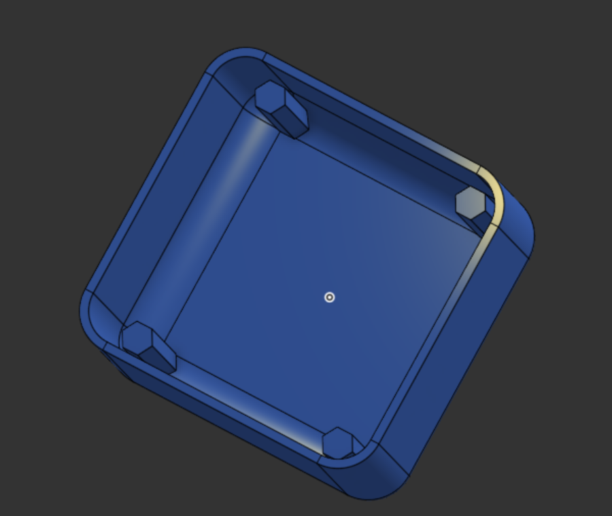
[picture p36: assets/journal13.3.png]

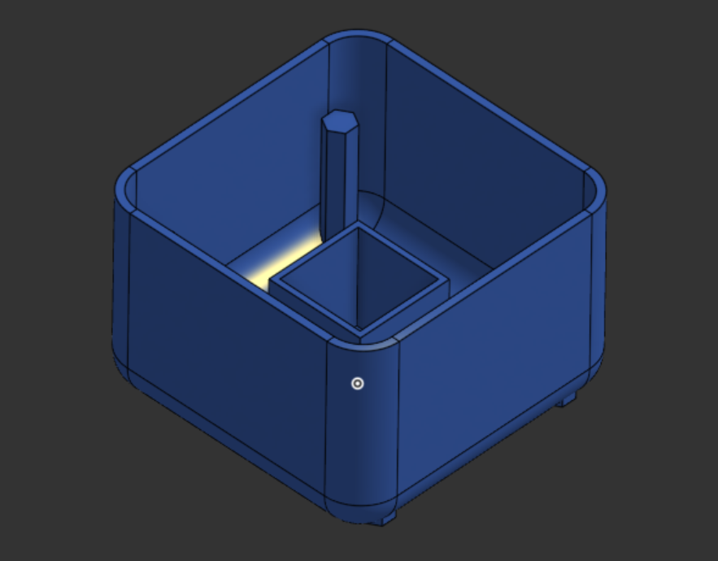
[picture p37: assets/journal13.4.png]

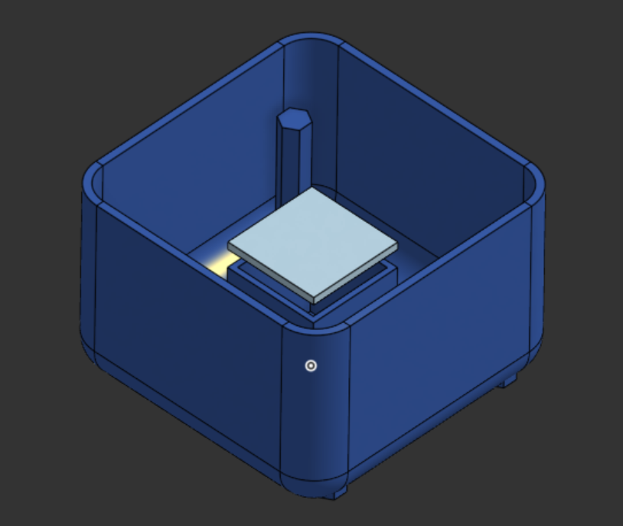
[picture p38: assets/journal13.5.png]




------
# date:19/08/2026
# time spent:1.5hr
## description:
I have two esp8266 and oled, instead of simulating the esp8266 I'm writing the firmware for the S3 watch and testing directly in the hardware I bought for previous projects. The firmware (main.ino i) wrote will show the value from the S3 cube. Currently it has a booting text like UI with shows the initial text But the final one I planned will have the menu like UI. And can be controlled by the push buttons in the PCB itself.
Next is to create a UI which is controlled by the push buttons and also to make a good UI for the S3 watch.

## images:
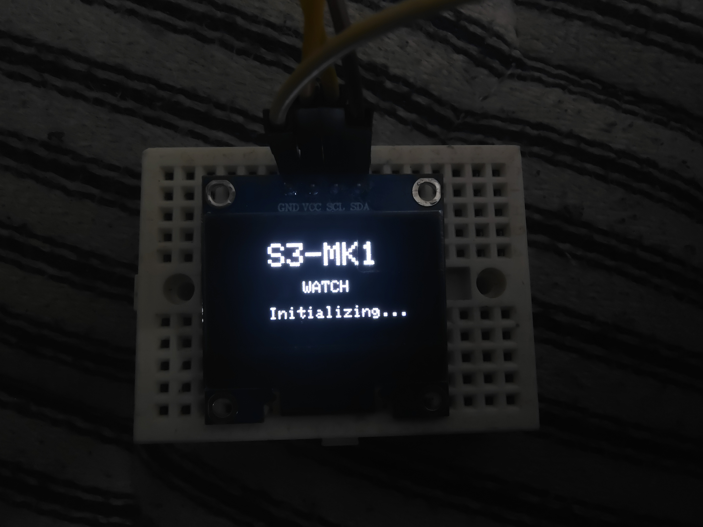
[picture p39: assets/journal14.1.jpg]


------
# date:22/08/2026
# time spent:1.5hr
## description:
After booting text now i'm showing the menu like screen, it's not fully feels like menu but now it's better with a table like UI showing all the data got from the S3 cube. I updated with some formating in the table like UI (you can see in the gif below). Now it's auto showing the various data but in the full version of the code there will be push button navigation where the S3 can be controlled from the S3 watch itself. Next is to upgrade this firmware and to create a CAD for the watch. And I'm also thinking to simulate S3 cube in online, Because I don't have all the required sensors for this.

## images:
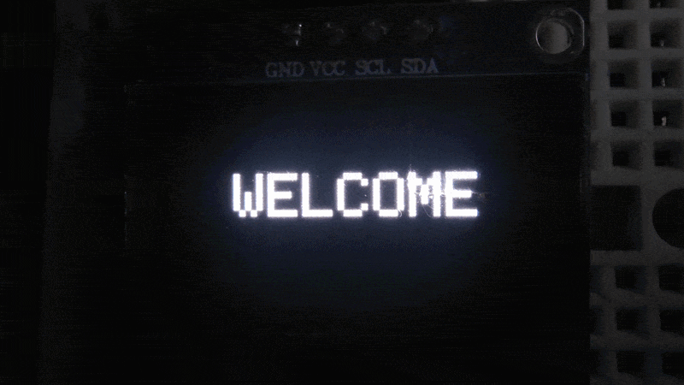
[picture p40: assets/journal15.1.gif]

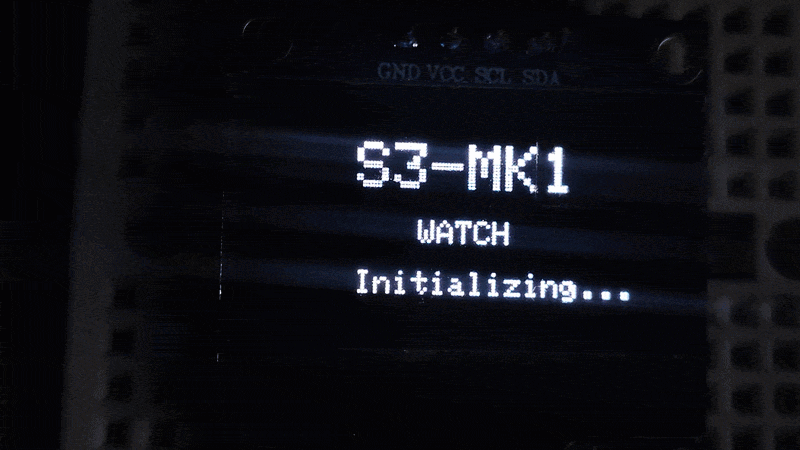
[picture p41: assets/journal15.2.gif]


------
# date:22/08/2026
# time spent:1.5hr
## description:
I started making the enlosure for S3 watch, I got all the measurements from the PCB using the measurement tool in KiCAD, measurements are below,
```
width : 27mm
height : 40mm
space for buttons : 10mm height x 10mm width (each side two buttons)
space for led : 10mm side left x 10mm right side (keep in middle)
space for display :
height : 28mm
width : 27.30
```
Using the above measurements I completed the sketch for PCB outer and inner diagrams, and using the extrusion tool I created the front plate (which is front side of the case) and side enclosure for the case. The front plate has spaces for buttons and status LEDs.
Next is to create the back plate and mechanism to place backplate and attaching strap for the S3 watch.
## images:
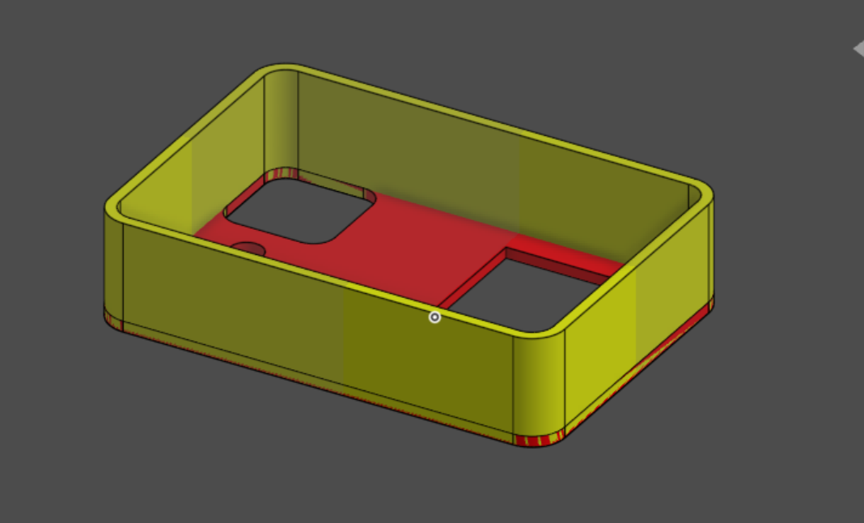
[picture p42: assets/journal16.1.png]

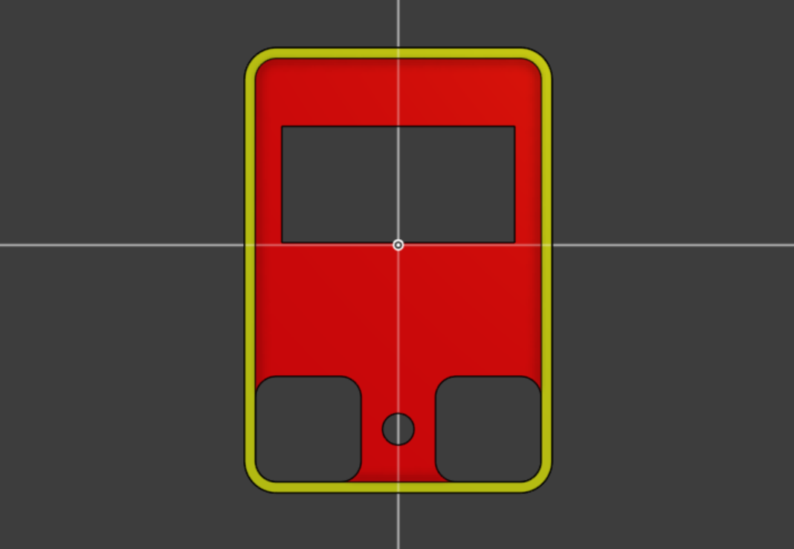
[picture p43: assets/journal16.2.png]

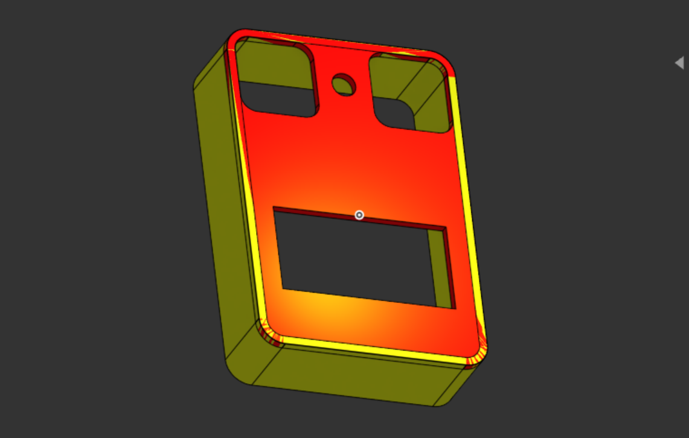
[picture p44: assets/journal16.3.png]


------
# date:23/08/2026
# time spent:1hr
## description:
I added legs for attaching the strap, I research about the legs for different sized watch straps. Since we are with 20mm strap, there's a table with all the size list. The spring which holds the strap is called "spring bar". The chart name is "Spring Bat size and dimentions" using this chart I created the legs with the necessary holes for length spring to hold the strap. I also thought of adding frame like structure for legs. Next is to create the frame and to create bitmaps for the menu UI and test it.
## images:



------
# date:23/08/2026
# time spent:1hr
## description:
I created few static and animated bitmaps for the S3 watch using lopaka webapp. Created home text and home animation along with the armed to disarmed animation and disarmed to armed animation for the S3 Cube. Next is to test it with the esp and oled hardware I set up shown in previous journals.
## images:
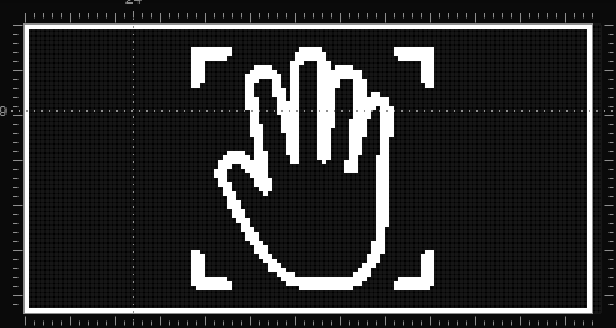
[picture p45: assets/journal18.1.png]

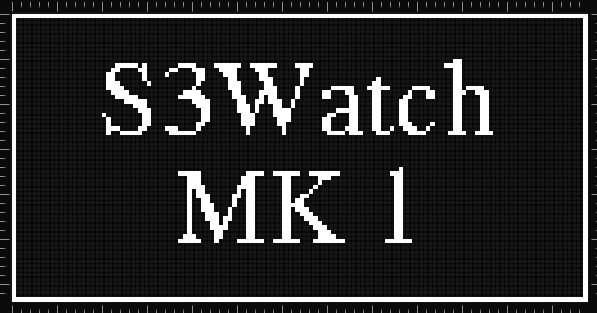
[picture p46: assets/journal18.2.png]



------
# date:23/08/2026
# time spent:1.5hr
## description:
I wrote a firmware for S3 watch with menu interface which can be controlled by the terminal, my hardware setup broke now the oled is not working so I'm using wokwi for testing this firmware.. it's working fine with the esp and oled in wokwi. This UI contains 4 menu items and 4 inner menu items, next I will be updating the menu UI. Bitmaps will be working fine in real hardware but in wokwi it's not working since it's just a simulation website, Bitmaps are heavy for the simulation.
## images:


------
# date:23/08/2026
# time spent:1.5hr
## description:
Now the final firmware has menu UI :) navigation is done, and it has status update as well. Like online status will be in blinking state if it's connected to S3 cube. And user can navigate it with push buttons (now it's in terminal). Next is to test this in real hardware once I print the PCB. I will be updating here when I get my PCB after printing :)
## images:


------

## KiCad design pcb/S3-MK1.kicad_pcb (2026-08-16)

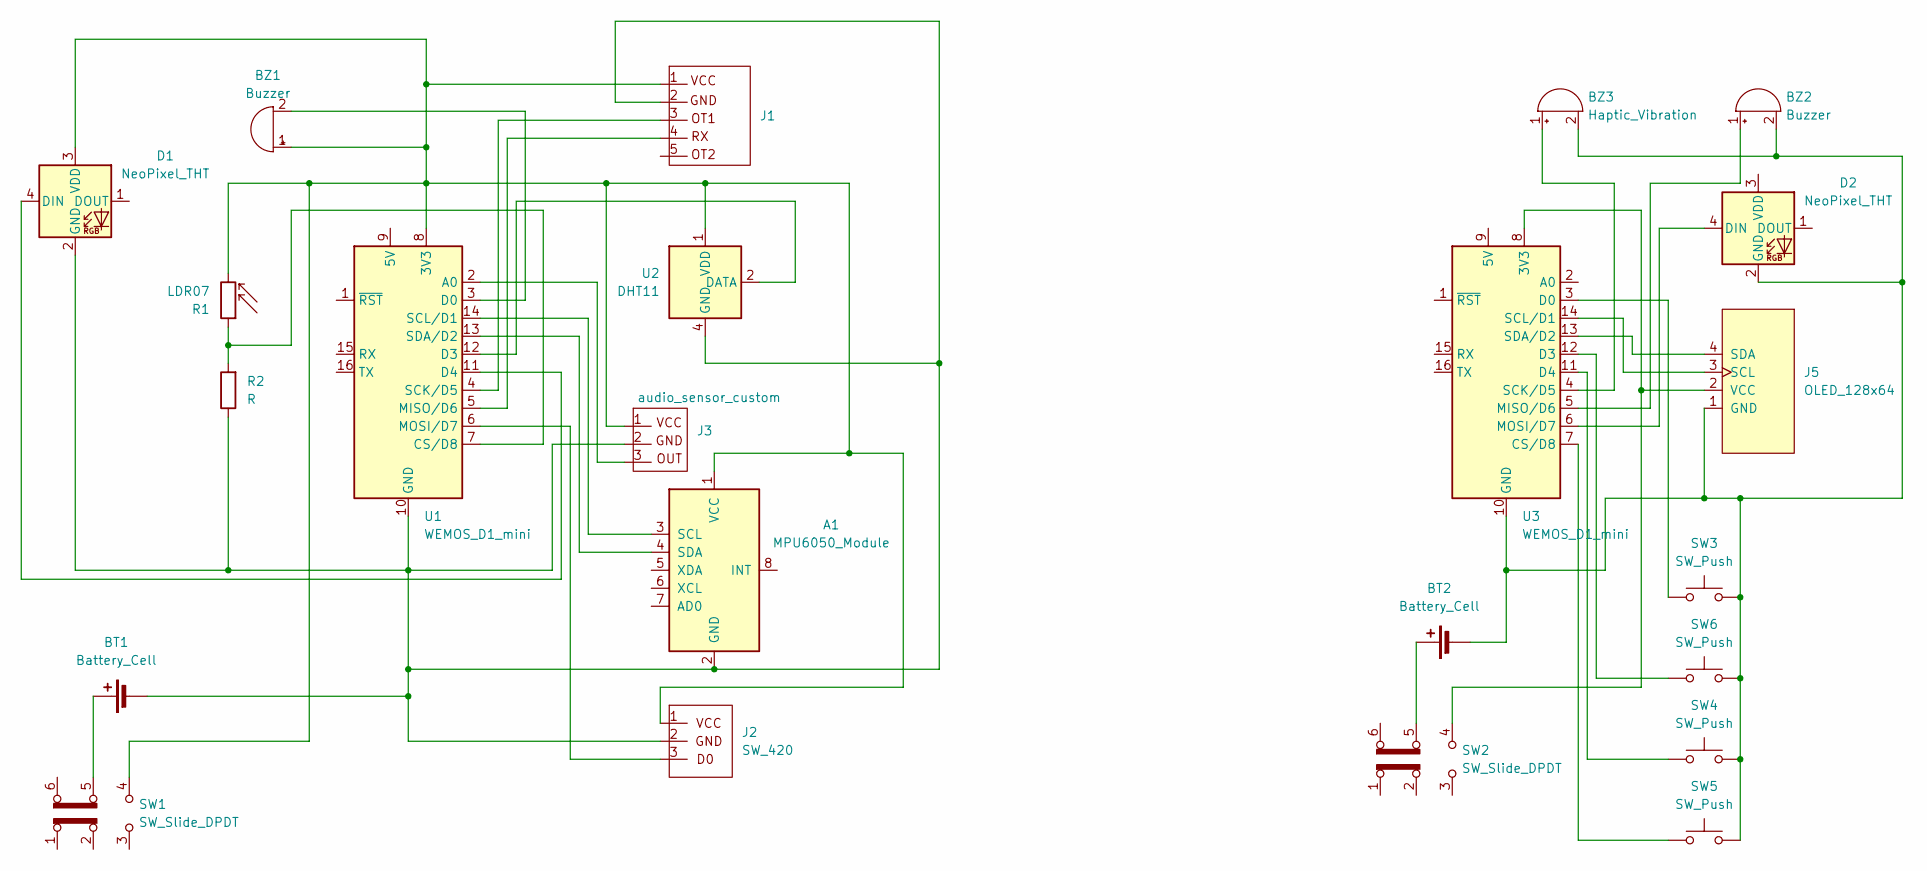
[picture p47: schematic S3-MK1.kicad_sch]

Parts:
A1: MPU6050_Module
BT1, BT2: Battery_Cell; Battery_LiPo_Custom
BZ1: Buzzer; Buzzer_TDK_PS1240P02BT_D12.2mm_H6.5mm
BZ2: Buzzer; MagneticBuzzer_Kingstate_KCG0601
BZ3: Haptic_Vibration; MagneticBuzzer_Kingstate_KCG0601
D1, D2: NeoPixel_THT; LED_SK6812_PLCC4_5.0x5.0mm_P3.2mm
J1: LD2420_custom
J2: SW_420; Vibration_sensor_SW420_custom
J3: audio_sensor_custom; Audio_sensor_custom
J5: OLED_128x64
R1: LDR07; R_LDR_5.1x4.3mm_P3.4mm_Vertical
R2: R; R_Axial_DIN0204_L3.6mm_D1.6mm_P5.08mm_Horizontal
SW1, SW2: SW_Slide_DPDT; SW_CK_JS202011CQN_DPDT_Straight
SW3, SW4, SW5, SW6: SW_Push; SW_PUSH_1P1T_6x3.5mm_H4.3_APEM_MJTP1243
U1, U3: WEMOS_D1_mini; WEMOS_D1_mini_light
U2: DHT11; Aosong_DHT11_5.5x12.0_P2.54mm

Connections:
unnamed: A1.2 (GND), BT1.2 (-), D1.2 (GND), J1.2 (GND), J2.2 (GND), J3.2, R2.1, U1.10 (GND), U2.4 (GND)
unnamed: A1.3 (SCL), U1.14 (SCL/D1)
unnamed: A1.4 (SDA), U1.13 (SDA/D2)
unnamed: A1.1 (VCC), BZ1.1 (+), D1.3 (VDD), J1.1 (VCC), J2.1 (VCC), J3.1, R1.2, SW1.4 (A), U1.8 (3V3), U2.1 (VDD)
unnamed: BT1.1 (+), SW1.5 (B)
unnamed: BT2.1 (+), SW2.5 (B)
unnamed: BT2.2 (-), BZ2.2 (-), BZ3.2 (-), D2.2 (GND), J5.1 (GND), SW3.2, SW4.2, SW5.2, SW6.2, U3.10 (GND)
unnamed: BZ1.2 (-), U1.3 (D0)
unnamed: BZ2.1 (+), U3.5 (MISO/D6)
unnamed: BZ3.1 (+), U3.4 (SCK/D5)
unnamed: D1.4 (DIN), U1.11 (D4)
unnamed: D2.4 (DIN), U3.6 (MOSI/D7)
unnamed: J1.4, U1.5 (MISO/D6)
unnamed: J1.3 (RX), U1.4 (SCK/D5)
unnamed: J2.3 (D0), U1.6 (MOSI/D7)
unnamed: J3.3, U1.2 (A0)
unnamed: J5.3 (SCL), U3.14 (SCL/D1)
unnamed: J5.4 (SDA), U3.13 (SDA/D2)
unnamed: J5.2 (VCC), SW2.4 (A), U3.8 (3V3)
unnamed: R1.1, R2.2, U1.7 (CS/D8)
unnamed: U1.12 (D3), U2.2 (DATA)
unnamed: SW5.1, U3.7 (CS/D8)
unnamed: SW3.1, U3.3 (D0)
unnamed: SW6.1, U3.12 (D3)
unnamed: SW4.1, U3.11 (D4)

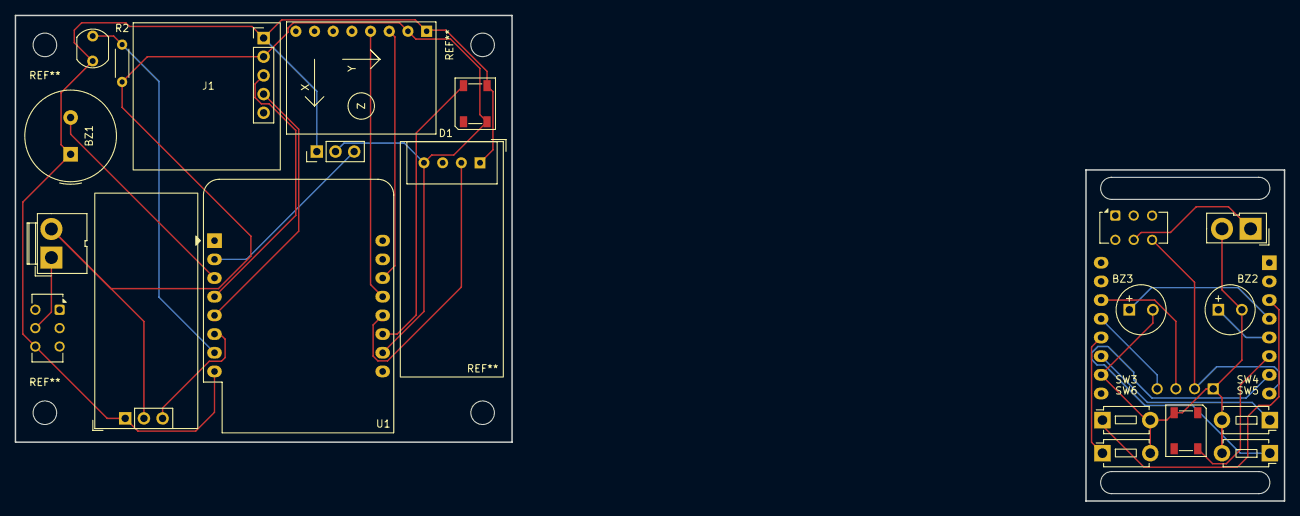
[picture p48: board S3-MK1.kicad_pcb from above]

Board: 2 copper layers, 172.5 x 66.0 mm, 23 parts (1 on the bottom side), 25 nets.

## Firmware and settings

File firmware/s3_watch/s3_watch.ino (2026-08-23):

#include <Wire.h>
#include <Adafruit_GFX.h>
#include <Adafruit_SSD1306.h>

#define SCREEN_WIDTH 128
#define SCREEN_HEIGHT 64

#define OLED_SDA 21
#define OLED_SCL 22
#define OLED_ADDRESS 0x3C

Adafruit_SSD1306 display(SCREEN_WIDTH, SCREEN_HEIGHT, &Wire, -1);

float temperature = 27.4;
float humidity = 61.0;
int lightLevel = 184;
bool motionDetected = false;
bool vibrationDetected = false;

enum MenuState {MENU_MAIN,MENU_SENSORS,MENU_SYSTEM,MENU_SETTINGS,MENU_ABOUT};

MenuState currentMenu = MENU_MAIN;
int menuSelection = 0;
const int menuItems = 4;
String mainMenuItems[] = {"Sensors", "System", "Settings", "About"};

unsigned long lastUpdate = 0;
const unsigned long UPDATE_INTERVAL = 1000;

unsigned long lastBlinkTime = 0;
bool blinkState = false;
const unsigned long BLINK_INTERVAL = 500;

bool inSubMenu = false;

void drawTopBar(const char* title
{
  display.fillRect(0, 0, SCREEN_WIDTH, 10, SSD1306_WHITE);
  display.setTextColor(SSD1306_BLACK);
  display.setTextSize(1);
  display.setCursor(2, 2);
  display.print(title);
  display.drawLine(0, 10, SCREEN_WIDTH, 10, SSD1306_WHITE);
}

void drawBottomBar(const char* text
{
  display.fillRect(0, SCREEN_HEIGHT - 10, SCREEN_WIDTH, 10, SSD1306_WHITE);
  display.setTextColor(SSD1306_BLACK);
  display.setTextSize(0);
  display.setCursor(2, SCREEN_HEIGHT - 8);
  display.print(text);
}

void drawMenuItem(int y, const char* text, bool selected, bool isLast = false
{
  if (selected
{
    display.fillRect(0, y, SCREEN_WIDTH, 10, SSD1306_WHITE);
    display.setTextColor(SSD1306_BLACK);
    
    display.fillTriangle(
      SCREEN_WIDTH - 10, y + 2,
      SCREEN_WIDTH - 4, y + 5,
      SCREEN_WIDTH - 10, y + 8,
      SSD1306_BLACK
    );
  } else {
    display.setTextColor(SSD1306_WHITE);
  }
  
  display.setTextSize(1);
  display.setCursor(4, y + 1);
  display.print(text);
  
  if (!isLast
{
    display.drawLine(0, y + 10, SCREEN_WIDTH, y + 10, SSD1306_WHITE);
  }
}

void showMainMenu(
{
  display.clearDisplay();
  
  drawTopBar("S3-MK1 MENU");
  
  int startY = 14;
  for (int i = 0; i < menuItems; i++
{
    bool isSelected = (i == menuSelection);
    bool isLast = (i == menuItems - 1);
    drawMenuItem(startY + (i * 11), mainMenuItems[i].c_str(), isSelected, isLast);
  }
  
  drawBottomBar("[1] Up  [2] Down  [3] Select");
  display.display();
}

void showSensorsMenu(
{
  display.clearDisplay();
  
  drawTopBar("SENSORS");
  
  display.setTextSize(1);
  display.setTextColor(SSD1306_WHITE);
  
  int yPos = 14;
  
  display.setCursor(4, yPos);
  display.print("Temp:");
  display.setCursor(80, yPos);
  display.print(temperature, 1);
  display.print(" C");
  display.drawLine(0, yPos + 10, SCREEN_WIDTH, yPos + 10, SSD1306_WHITE);
  
  yPos += 12;
  display.setCursor(4, yPos);
  display.print("Humidity:");
  display.setCursor(80, yPos);
  display.print(humidity, 1);
  display.print(" %");
  display.drawLine(0, yPos + 10, SCREEN_WIDTH, yPos + 10, SSD1306_WHITE);
  
  yPos += 12;
  display.setCursor(4, yPos);
  display.print("Light:");
  display.setCursor(80, yPos);
  display.println(lightLevel);
  display.drawLine(0, yPos + 10, SCREEN_WIDTH, yPos + 10, SSD1306_WHITE);
  
  yPos += 12;
  display.setCursor(4, yPos);
  display.print("Motion:");
  display.setCursor(80, yPos);
  if (motionDetected
{
    display.setTextColor(SSD1306_WHITE);
    display.fillRect(75, yPos, 50, 9, SSD1306_WHITE);
    display.setTextColor(SSD1306_BLACK);
    display.print("DETECTED");
    display.setTextColor(SSD1306_WHITE);
  } else {
    display.print("Clear");
  }
  
  drawBottomBar("[0] Back  [u] Update");
  
  display.display();
}

void showSystemMenu(
{
  display.clearDisplay();
  
  drawTopBar("SYSTEM INFO");
  
  display.setTextSize(1);
  display.setTextColor(SSD1306_WHITE);
  
  int yPos = 14;
  
  display.setCursor(4, yPos);
  display.print("Device:");
  display.setCursor(80, yPos);
  display.println("S3-MK1");
  display.drawLine(0, yPos + 10, SCREEN_WIDTH, yPos + 10, SSD1306_WHITE);
  
  yPos += 12;
  display.setCursor(4, yPos);
  display.print("Firmware:");
  display.setCursor(80, yPos);
  display.println("v0.1.0");
  display.drawLine(0, yPos + 10, SCREEN_WIDTH, yPos + 10, SSD1306_WHITE);
  
  yPos += 12;
  display.setCursor(4, yPos);
  display.print("Status:");
  display.setCursor(80, yPos);
  if (blinkState
{
    display.fillRect(75, yPos, 50, 9, SSD1306_WHITE);
    display.setTextColor(SSD1306_BLACK);
    display.print("ONLINE");
    display.setTextColor(SSD1306_WHITE);
  } else {
    display.print("Online");
  }
  display.drawLine(0, yPos + 10, SCREEN_WIDTH, yPos + 10, SSD1306_WHITE);
  
  yPos += 12;
  display.setCursor(4, yPos);
  display.print("Uptime:");
  display.setCursor(80, yPos);
  display.print(millis() / 1000);
  display.println("s");
  
  drawBottomBar("[0] Back");
  
  display.display();
}

void showSettingsMenu(
{
  display.clearDisplay();
  
  drawTopBar("SETTINGS");
  
  display.setTextSize(1);
  display.setTextColor(SSD1306_WHITE);
  
  int yPos = 14;
  
  const char* items[] = {"Update Interval", "Brightness", "Auto-scroll", "Reset Settings"};
  
  for (int i = 0; i < 4; i++
{
    bool isSelected = (i == menuSelection % 4);
    
    if (isSelected
{
      display.fillRect(0, yPos, SCREEN_WIDTH, 10, SSD1306_WHITE);
      display.setTextColor(SSD1306_BLACK);
      display.fillTriangle(
        SCREEN_WIDTH - 10, yPos + 2,
        SCREEN_WIDTH - 4, yPos + 5,
        SCREEN_WIDTH - 10, yPos + 8,
        SSD1306_BLACK
      );
    } else {
      display.setTextColor(SSD1306_WHITE);
    }
    
    display.setCursor(4, yPos + 1);
    display.print(i + 1);
    display.print(". ");
    display.print(items[i]);
    
    display.setTextColor(SSD1306_WHITE);
    display.drawLine(0, yPos + 10, SCREEN_WIDTH, yPos + 10, SSD1306_WHITE);
    
    yPos += 11;
  }
    
  display.display();
}

void showAboutMenu(
{
  display.clearDisplay();
  
  drawTopBar("ABOUT");
  
  display.setTextSize(1);
  display.setTextColor(SSD1306_WHITE);
  
  int yPos = 14;
  
  display.setCursor(20, yPos);
  display.println("S3-MK1");
  
  display.drawLine(0, yPos + 12, SCREEN_WIDTH, yPos + 12, SSD1306_WHITE);
  
  yPos += 16;
  display.setCursor(15, yPos);
  display.println("ESP32 Smart Watch");
  
  yPos += 12;
  display.setCursor(15, yPos);
  display.println("OLED 128x64");
  
  yPos += 12;
  display.setCursor(20, yPos);
  
  display.drawRect(1, 12, SCREEN_WIDTH - 2, 40, SSD1306_WHITE);
  
  
  display.display();
}

void updateFakeValues(
{
  temperature += random(-3, 4) * 0.1;
  humidity += random(-5, 6) * 0.1;
  lightLevel += random(-15, 16);
  
  if (lightLevel < 0) lightLevel = 0;
  if (lightLevel > 1023) lightLevel = 1023;
  
  motionDetected = random(0, 10) > 7;
  vibrationDetected = random(0, 10) > 8;
}

void displayWelcomeScreen(
{
  display.clearDisplay();
  
  for (int i = 0; i < 3; i++
{
    display.clearDisplay();
    display.setTextSize(2);
    display.setTextColor(SSD1306_WHITE);
    display.setCursor(15, 20);
    display.println("S3-MK1");
    display.setTextSize(1);
    display.setCursor(40, 40);
    display.print("Loading");
    for (int j = 0; j <= i; j++
{
      display.print(".");
    }
    display.display();
    delay(500);
  }
  
  display.clearDisplay();
  display.setTextSize(2);
  display.setTextColor(SSD1306_WHITE);
  display.setCursor(15, 20);
  display.println("S3-MK1");
  display.setTextSize(1);
  display.setCursor(30, 40);
  display.println("Ready!");
  display.display();
  delay(1000);
}

void handleSerialCommands(
{
  if (Serial.available() > 0
{
    char cmd = Serial.read();
    
    while (Serial.available() > 0
{
      Serial.read();
    }
    switch (cmd
{
      case '1':
        if (currentMenu == MENU_MAIN || currentMenu == MENU_SETTINGS
{
          menuSelection--;
          if (menuSelection < 0
{
            menuSelection = (currentMenu == MENU_MAIN) ? menuItems - 1 : 3;
          }
          Serial.print(">> Selection: ");
          Serial.println(menuSelection + 1);
        }
        break;
        
      case '2':
        if (currentMenu == MENU_MAIN || currentMenu == MENU_SETTINGS
{
          menuSelection++;
          if (menuSelection >= ((currentMenu == MENU_MAIN) ? menuItems : 4)
{
            menuSelection = 0;
          }
          Serial.print(">> Selection: ");
          Serial.println(menuSelection + 1);
        }
        break;
        
      case '3':
        if (currentMenu == MENU_MAIN
{
          switch (menuSelection
{
            case 0:
              currentMenu = MENU_SENSORS;
              Serial.println(">> Entering Sensors Menu");
              break;
            case 1:
              currentMenu = MENU_SYSTEM;
              Serial.println(">> Entering System Menu");
              break;
            case 2:
              currentMenu = MENU_SETTINGS;
              menuSelection = 0;
              Serial.println(">> Entering Settings Menu");
              break;
            case 3:
              currentMenu = MENU_ABOUT;
              Serial.println(">> Entering About Menu");
              break;
          }
        }
        break;
        
      case '0':
        if (currentMenu != MENU_MAIN
{
          currentMenu = MENU_MAIN;
          menuSelection = 0;
          Serial.println(">> Returning to Main Menu");
        }
        break;
        
      case 'u':
      case 'U':
        updateFakeValues();
        Serial.println(">> Sensors Updated");
        break;
        
      case 'h':
      case 'H':
        Serial.println("S3-MK1 COMMANDS");
        break;
        
      default:
        if (cmd != '\n' && cmd != '\r'
{
          Serial.println("Unknown command. Press 'h' for help.");
        }
        break;
    }
  }
}

void setup() 
{
  Serial.begin(115200);
  randomSeed(micros());
  
  Wire.begin(OLED_SDA, OLED_SCL);
  
  if (!display.begin(SSD1306_SWITCHCAPVCC, OLED_ADDRESS)
{
    Serial.println("SSD1306 allocation failed");
    for(;;);
  }
  
  display.clearDisplay();
  displayWelcomeScreen();
  showMainMenu();
  
  Serial.println("S3-MK1 SMART WATCH");
  Serial.println("Serial Menu Interface Active");
  Serial.println("Press 'h' for help");
}

void loop(
{
  if (millis() - lastUpdate >= UPDATE_INTERVAL
{
    lastUpdate = millis();
    updateFakeValues();
  }
  
  if (millis() - lastBlinkTime >= BLINK_INTERVAL
{
    lastBlinkTime = millis();
    blinkState = !blinkState;
  }
  
  handleSerialCommands();
  
  switch (currentMenu) 
  {
    case MENU_MAIN:
      showMainMenu();
      break;
    case MENU_SENSORS:
      showSensorsMenu();
      break;
    case MENU_SYSTEM:
      showSystemMenu();
      break;
    case MENU_SETTINGS:
      showSettingsMenu();
      break;
    case MENU_ABOUT:
      showAboutMenu();
      break;
  }
  
  delay(100);
}

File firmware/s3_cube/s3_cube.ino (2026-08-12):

#include <Wire.h>
#include <Adafruit_MPU6050.h>
#include <Adafruit_Sensor.h>
#include <DHT.h>
#include <SoftwareSerial.h>

SoftwareSerial ld2410(LD2410_RX, LD2410_TX);

#define DHT_TYPE DHT11

DHT dht(DHT_PIN, DHT_TYPE);

#define MPU_SDA D2
#define MPU_SCL D1

#define LD2410_RX D5
#define LD2410_TX D6

#define VIBRATION_PIN D7

#define DHT_PIN D3

#define LDR_PIN A0

void setup() {
  Serial.begin(115200);
  delay(1000);
  Serial.println();
  Serial.println("------");
  Serial.println("S3-MK1 STARTING!");
  Serial.println("------");

  initGPIO();
}

void initGPIO(){
  pinMode(VIBRATION_PIN, INPUT);
  Serial.println("GPIO Starting");
}

void initMPU6050() {
  Wire.begin(MPU_SDA, MPU_SCL);
  if (!mpu.begin()) 
  {
    Serial.println("MPU6050 is not working!");
  }
  else 
  {
    Serial.println("MPU6050 initialized");
  }
}

void readMPU6050() {
  sensors_event_t accel;
  sensors_event_t gyro;
  sensors_event_t temp;

  mpu.getEvent(&accel, &gyro, &temp);

  Serial.print("AX -");
  Serial.print(accel.acceleration.x);
  Serial.print("AY -");
  Serial.print(accel.acceleration.y);
  Serial.print("AZ -");
  Serial.print(accel.acceleration.z);
}

void intiDHT11() {
  dht.begin();
  Serial.println("DHT11 initialized");
}

void readDHT() {
  float temperature = dht.readTemperature();
  float humidity = dht.readHumidity();

  if (isnan(temperature) || isnan(humidity)) 
  {
    Serial.println("DHT is not working!");
    return;
  }
  Serial.print("T - ");
  Serial.print(temperature);
  Serial.print("H - ");
  Serial.print(humidity);
}

void readLDR() {
  int light = analogRead(LDR_PIN);

  Serial.print("LDR - ");
  Serial.println(light);
}

void initSW420() {
  pinMode(VIBRATION_PIN, INPUT);
  Serial.println("SW-420 initialized");
}

void readSW420() {
  bool vibration = digitalRead(VIBRATION_PIN);
  Serial.print("VIB - ");
  if (vibration)
  {
    Serial.println("DETECTED");
  }
  else
  {
    Serial.println("NONE");
  }
}

void initLD2410() {
  ld2410.begin(256000);
  Serial.println("LD2410 initialized");
}

void readLD2410() {
  while (ld2410.available())
  {
    uint8_t data = id2410.read();

    Serial.print(data, HEX);
    Serial.print(" ");
  }
  Serial.println();
}

void readSensors() {
  readMPU6050();
  readDHT();
  readLDR();
  readSW420();
  readLD2410();
}

void loop() {
  Serial.println("S3-MK1 RUNNING...")
  readSensors();
  delay(500);

}

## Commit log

2026-08-04 added pcb and journal 3
    [S3-MK1.kicad_pcb, S3-MK1.kicad_sch]
2026-08-09 journal 4 : added, connected new sym, footprints
    [S3-MK1.kicad_pcb, S3-MK1.kicad_sch]
2026-08-09 journal 5 : PCB footprints placement
    [S3-MK1.kicad_pcb]
2026-08-10 routed the pcb, solved all errors, journal 6
    [S3-MK1.kicad_pcb]
2026-08-12 journal 7 : added new components, firmware
    [S3-MK1.kicad_pcb, S3-MK1.kicad_sch]
2026-08-13 added journal 8, pcb files, libs
    [S3-MK1.kicad_pcb, S3-MK1.kicad_sch]
2026-08-13 journal 9, added S3 watch PCB, files
    [S3-MK1.kicad_pcb, S3-MK1.kicad_sch]
2026-08-16 journal 10, added pcb, complete s3 watch files
    [S3-MK1.kicad_pcb]
2026-08-17 added journal 11, cad sketch, pcb
2026-08-18 added CAD files, journal 13
    [s3-cube-base-enclosure.3mf, s3-cube-base-enclosure.step, s3-cube-base-enclosure.stl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]
2026-08-22 added S3 watch enclosure, journal
2026-08-23 updated S3 watch enclosure CAD with 20mm lugs, journal
2026-08-23 added production files cad and gerbers
    [S3-watch-PCB-back-plate.3mf, S3-watch-PCB-back-plate.step, S3-watch-PCB-back-plate.stl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]
2026-08-23 added production files, cad, gerbers, final firmware, new journals
    [S3-MK1.kicad_pcb_bom.csv, S3-MK1.kicad_pcb_positions.csv]
2026-08-24 added BOM, assets, updated README
    [BOM.xlsx]
